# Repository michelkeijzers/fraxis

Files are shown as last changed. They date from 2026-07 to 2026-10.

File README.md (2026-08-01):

# README

This project's personal goal is to learn more about ESP32 with ESP-IDF programming.

The project is a retro style computer with instead of a screen a 5x72 LED matrix, two joysticks (for each player), an 20x4 display, a display for time and scoring per player and a button and some LEDs.
At a later stage also sound will be incorporated (passive buzzer, I2s microphone and speaker, mono).

The idea is to be able to show demos, games and tools.

# DOCUMENTATION

In the Docs folder, UML diagrams can be found.
Also an extensive document (Fraxis.odt) shows the design decisions and more information about the project.

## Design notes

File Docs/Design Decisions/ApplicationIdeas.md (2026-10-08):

# Application Ideas

## GAMES

### Amoeba

Both players try to protect their base from the amoeba. It starts at the center. It grows whatever are no his. Players can shoot with button length press to decide the speed and thus location of the defense.
When the amoeba reaches a player, the player loses.
Points based on amoeba growth on enemy side

### Reaction time

Led Screen lights up, players press button as far as possible.

### Pixel chaser

Players move towards lighted pixels to get points. Different colors. Pixels fade. Faded pixels explode lowering or pausing speed.

### Stacking Game

One line moves from left to right and then the next row back. The player has to stack the next row on top of the previous one. When the player misses, the next row is smaller. When the player misses too much, he loses.

Maybe horizontal is also fine, starting of with a very wide row.

See https://www.youtube.com/shorts/zlKPKK3Qink

### Frogger

Tbd
Scrolling probably works best

### Line Racer , Car racer

Tbd
Optionally with turns

### Tetris

5 columns or windowed.

### Tunnel navigator

Like car racer but horizontal. More irregular pattern and various heights.

Helicopter rescue

The players have to pick up people to be rescued and bring them back to base.
Max 6 can be picked up and loading and unloading takes time.
The players have one common pool of testers. The helicopters cannot hit each other.

### Flow

Like android game. Windowed

Geography

Educational
Fly over a highly zoomed in county and find city shown in display selected as dot. Windowed.

### Guess the country

Educational
Fly over a highly zoomed in and guess the country from a list in the display.
Windowed

### 1D pong

Really one d Pong, over five rows same

### Dungeon, Dare jump

Player starts under rough wall moving down. Left right to lower. Platforms to land on. When no platform, dead.
Platforms like crumbling stone, fixed wood, moving left or right platforms, trampoline.
Landing on spikes or spikes at top hitting, losing one life.
Source xiamen

### Tank war

starting at home, tank moves. Scrollable. Walls can be shot, enemy tanks as well. Enemy tanks come and change direction at wall hit. Impenetrable blocks. When hit, started from home again. Enemy tanks can be shot in two stages.
Source xiamen

### Fishing Captain

Horizontal. Boat on top center, not movable. Throw nets or catch fishes with bubbles. At bottom row a pearl opens up at times for points. Be aware of bombs. Goal is to catch certain fishes in time. Colors can be used
Show on side what amount and types of fishes are needed. Two players with two boats on each half center.
Source xiamen

### Five in a row

Scrollable.
Source xiamen

### Ball battle

Evading planets and comets, eating balls.
Eat smaller balls only, in Fraxis use intensity.
Maybe scrollable.
Fixed full board size
Source xiamen

### (Dragon soul ) tower defense

Various types of defense towers have to be placed. Various enemies coming in waves each with hp. Some enemies are resistant against certain defense towers types.
Points by killing enemies can be used to buy more defense towers.
Broken through enemies cost a life.
Source xiamen

### 2048

Check if colors and intensiteit can be used
Move left right up or down, 2 is added at random left or right I think
Source xiamen

### Intellectual box

Puzzle

Move over kind of walls, 4 directions by rolling over or rotate, forming a 1x1 or 2x1 form. Find and fall into destination hole. Red Square are not allowed to land, don't get with one pixel over the edge.
Score is amount of moves.

Source xiamen

### Surround Jett

Puzzle
A rabbit wants to escape. Rabbit moves, you place fence. Either rabbit escapes or is trapped, ie cannot move. Score is amount of moves.
Source xiamen

### Flood

A river in the center. Players shoot by using left and right joystick press time for distance. When wall is hit, enemy or friendly, water slowly spreads if connected to empty spot.
Some pixels can result in bigger breaches.
Also a wall pixel can have hit points.

### Base shooter

Players can shoot rockets via the five lanes. When two rockets hit they explode.
When enemy rocket reaches enemy, 1 point. Time based.
No more than a certain amount of rockets per player can be active. Then the player can not shoot.

### 1D Line Advancer

A line is shown in the middle. Alternately players use button joystick to add pressure to a ball.v when released, ball moves. When stopped at line moves toward other player. When line is at player s home, player loses.

### Rocket lander

A moon rocket has to be landed with limited energy and breaking enough. Too much brake, fuel empty and crash. Too less brake, hit velocity too high.

### Snake

Windowed

### Space invaders

Windowed

### Crossroads

Starting with one crossing. Player has to switch traffic lights. One main long road or maybe two or three. Tbd.
Cars come and go. Maybe different vehicles by colors having different speeds or acceleration speeds.
Level increase by more crossings.

### Maze

Tbd

### Pacman

Windowed

### Mine sweeper

Puzzle
Either 5x72 or less, or windowed.

### Find differences

Patterns, maybe more than two. Find differences in pixels, intensity
Source xiamen

### Mastermind

Tbd.

### Simon shows

Leds are shown for a short time. Player has to repeat it.

Maybe new pixels appear and disappear while players are adding their matching pixels.

### Roulette

Choose various types of bets with the Joystick placed on predefined spots on the led board. Joystick to select bet amounts shown on the tm display
Pressing a green area causes the player to end bets
When both players are finished, ball rolls over the first line with single numbers.

### Alien feeder

A line patterned alien moves down. To have it back off, the players have to select a puzzel with the same color as the lowest line of the alien.
In the free area pixels of random colors are shown, with at least one per five rows with the right color.
Selection a wrong color make the alien extend one line immediately.
When the alien r reaches a player, the other wins
The alien starts with one line and extends to each players directions.

### Pick the color

A color has to be picked. When switched, the lowest three led strips show way less, less, correct, more or wat more per red green and blue. Maybe only less, real or more is best
Time based

### Stock market

Five rows shows stocks, forecast etc.

### Company Tycoon

Columns show information.
Buy incoming goods, s sell outgoing
Get personnel, machines, space, marketing, customer forecast etc
Manual needed

### Summer Games

Like in commodore 64
Left right movement, starting slowly, going faster.

### Button Papegaai (Parrot?)

When players half of the led light, press button, release when off
Score is as soon as possible button press and release.
Over time, led leds light up and less intensity

## DEMOS

### Knight Rider

Typical. Speed and length of trace van be adapted by joystick.

### Galaxy

Blue and white and in-between dots show and fade.
Relaxing.
Alternatives: falling stars, suns, supernovas exploding.
Intensity and speed can be adapted by joystick. Button for intensity on off. When off, amount of lights is changed.

### Rainbow

Scrolling colors. Speed and diagonally speed can be adapted by joystick,.

### Matrix

Falling lines of rain

### Stroboscope

Joystick for light and speed.
Second joystick for off time and color mode? Or joystick button color mode.

### Conway game of life

Tbd

## TOOLS

### Color mixer

Joystick button for choosing rgb , direction for more or less.

### Led strip metronome

Tbd

### Banner

Text is entered by joystick. Banner shown on ledstrip. Joystick button changed color mode fixed, changing, and up down direction speed. Left right color.

Bluetooth keyboard

### Counter

Two users can use the joystick to increase our decrease their counter. Shown on tm1637 and on ledstrip.
Button also to increase.

### Countdown timer

Set by Joystick, digit by digit. Button to start. Time shown on ledstrip and display. Led strip also shows pixels decreasing to 0.

### Clock

Shows clock (date/time?)

### Simple draw

Joystick for direction. Button changes color.
Possibility to save it load pictures, not sure how.

### UTILITIES

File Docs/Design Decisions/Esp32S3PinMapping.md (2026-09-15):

# ESP32 Pin Management

## Kicad mismatch

There is a mismatch between both available symbols on the schema editor and the (single) foot print.

Below is the mapping which has been changed to support the correct foot print.

Order is top/bottom, left to right for a landscape placed ESP32 footprint.

| Footprint Name | Pin Nr | (Old) Schematics Name  | Function |
| --- | --- | --- | --- |
| (Bottom, left to right) | - | - | - |
| 3V3 | 1 | LNA_IN/RF | |
| 3V3 | 2 | VDD3P3 | |
| EN/RESET | 3 | | |
| GPIO4 | 4 | | |
| GPIO5 | 5 | GPIO0/BOOT | |
| GPIO6 | 6 | GPIO1/ADC1_CH0 | |
| GPIO7 | 7 | GPIO2/ADC1_CH1 | |
| GPIO15 | 8 | GPIO3/ADC1_CH2 | |
| GPIO16 | 9 | GPIO4/ADC1_CH3 | |
| GPIO17 | 10 | GPIO5/ADC1_CH4 | |
| GPIO18 | 11 | GPIO6/ADC1_CH5 | |
| GPIO8 | 12 | GPIO7/ADC1_CH6 | |
| GPIO3 | 13 | GPIO8/ADC1_CH7 | |
| GPIO46 | 14 | GPIO9/ADC1_CH8 | |
| GPIO9 | 15 | ?? | |
| GPIO10 | 16 | GPIO11/ADC2_CH0 | |
| GPIO11 | 17 | GPIO12/ADC2_CH1 | |
| GPIO12 | 18 | GPIO13/ADC2_CH2 | |
| GPIO13 | 19 | GPIO14/ADC2_CH3 | |
| GPIO14 | 20 | VDD3P3_RTC | |
| 5V | 21 | GPIO15/ADC2_CH4/XTAL.. | |
| GND | 22 | GPIO16/ADC2_CH5/XTAL.. | |
| (Top, right to left) | - | - | - |
| GND | 23 | GPIO17/ADC2_CH6 | |
| GND | 24 | GPIO18/ADC2_CH7 | |
| GPIO19 | 25 | | |
| GPIO20 | 26 | | |
| GPIO21 | 27 | GPIO21 | |
| GPIO47 | 28 | GPIO26/SPI_CS1 | |
| GPIO48 | 29 | VDD_SPI | |
| GPIO45 | 30 | GPIO27/SPIHD | |
| GPIO0 | 31 | GPIO28/SPIWP | |
| GPIO35 | 32 | GPIO29/SPICS0 | |
| GPIO36 | 33 | GPIO30/SPICLK | |
| GPIO37 | 34 | GPIO31/SPIQ | |
| GPIO38 | 35 | GPIO32/SPID | |
| GPIO39/MTCK | 36 | GPIO48/SPICLK_N | |
| GPIO40/MTDO | 37 | GPIO47/SPICLK_P | |
| GPIO41/MTDI | 38 | SPIO33 | |
| GPIO42/MTMS | 39 | SPIO34 | |
| GPIO02 | 40 | GPIO35 | |
| GPIO01 | 41 | GPIO36 | |
| GPIO44/UORXD | 42 | GPIO37 | |
| GPIO43/UOTXD | 43 | GPIO38 | |
| GND | 44 | GND | |

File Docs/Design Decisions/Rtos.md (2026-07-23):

# RTOS

# TASKS

Core 0: Time Critical
Core 1: Logic, UI, I/O, System

| Task | Contains | Core | Priority | Percentage | Notes |
| --- | --- | ---- | --- | --- | --- |
| LedStrips | WS2812 | 0 | Highest  | 5-15% | 60 Hz |
| Sound | MAX98357 speaker, INMP441 Mic, Passive Buzzer | 0 | High | 10-25% | 16 kHz, 16 bit, mono |
| I2C | MCP23017 (Joysticks, PinIO, LEDs, button), 2004 LCD | 1 | High | 3-10% | |
| Tm1637 | TM1637 (Central Panel, Player 1/2) | 1 | Medium | 2-6% | |
| Apps | Apps | 1 | Medium | 5-20% | |
| System | Menu, NVRAM, Logging, Settings | 1 | Low | 2-5% | |

# QUEUES

| Queue | Source | Destination  | Messages | Data | Notes |
| --- | --- | --- | --- | --- | --- |
| LedStripQueue | Apps | LedStrips | SetLeds | ledBuffer | - |
| | | | SetBrightness | level | - |
| SoundQueue | Apps | Sound | PlaySample | id | - |
| | | | Tone | frequency, duration | |
| | | | StopSound | | |
| | | | StartMic | | |
| | | | StopMic | | |
| I2CRequest | Apps, System | I2C | WriteLed | ledId, value | |
| | | | PrintLcd | line1, line2 | |
| | | | ClearLcd | | |
| I2CEvent | I2C | Apps, System | JoystickEvent | player, direction | |
| | | | ButtonEvent | id, pressed | |
| Tm1637 | Apps, System | Tm1637 | SetValue | id, value | |
| | | | SetTime | first, second | |
| System | System | Apps | RunApp | appId | |
| | Apps | System | ChangeSettings | Settings | |
| | | | UpdateHighscores | Highscores | |
| Logging | Any | System | Log | Source, type, logging text | Type = Error, warning, info, debug |

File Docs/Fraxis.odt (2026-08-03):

FRAXIS

Five Row Arcade eXperience
Interactive System

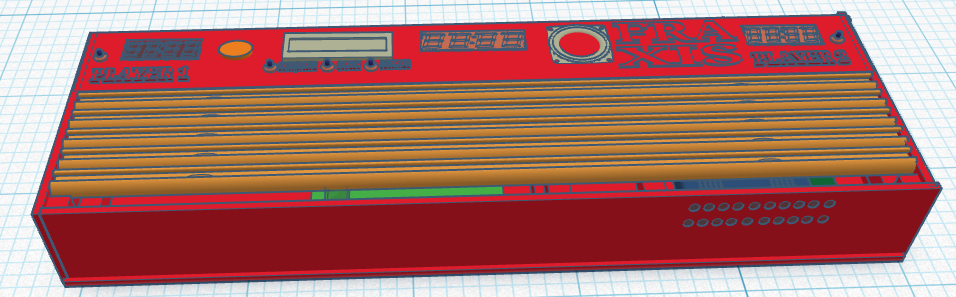
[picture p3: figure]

v0.12

Created by Michel Keijzers

Date July 7, 2026

Table of Content

1. Introduction (https://docs.google.com/document/d/1huFCTBTo_V-qLagU39WpXXM1eQROCzyZlzvM63dEwec/edit?tab=t.0)

2. Device (https://docs.google.com/document/d/1huFCTBTo_V-qLagU39WpXXM1eQROCzyZlzvM63dEwec/edit?tab=t.0)

3. Electrical (https://docs.google.com/document/d/1huFCTBTo_V-qLagU39WpXXM1eQROCzyZlzvM63dEwec/edit?tab=t.0)

4. Games (https://docs.google.com/document/d/1huFCTBTo_V-qLagU39WpXXM1eQROCzyZlzvM63dEwec/edit?tab=t.0)

4.1. Glossary (https://docs.google.com/document/d/1huFCTBTo_V-qLagU39WpXXM1eQROCzyZlzvM63dEwec/edit?tab=t.0)

4.2. Solo Games (https://docs.google.com/document/d/1huFCTBTo_V-qLagU39WpXXM1eQROCzyZlzvM63dEwec/edit?tab=t.0)

4.3. Two Player Games (https://docs.google.com/document/d/1huFCTBTo_V-qLagU39WpXXM1eQROCzyZlzvM63dEwec/edit?tab=t.0)

4.4. Both Solo/Two Player Games (https://docs.google.com/document/d/1huFCTBTo_V-qLagU39WpXXM1eQROCzyZlzvM63dEwec/edit?tab=t.0)

4.4.1. Pong (https://docs.google.com/document/d/1huFCTBTo_V-qLagU39WpXXM1eQROCzyZlzvM63dEwec/edit?tab=t.0)

4.4.1.1. Description (https://docs.google.com/document/d/1huFCTBTo_V-qLagU39WpXXM1eQROCzyZlzvM63dEwec/edit?tab=t.0)

4.4.1.2. Game Rules (https://docs.google.com/document/d/1huFCTBTo_V-qLagU39WpXXM1eQROCzyZlzvM63dEwec/edit?tab=t.0)

4.4.1.3. Scoring (https://docs.google.com/document/d/1huFCTBTo_V-qLagU39WpXXM1eQROCzyZlzvM63dEwec/edit?tab=t.0)

4.4.1.4. UI (https://docs.google.com/document/d/1huFCTBTo_V-qLagU39WpXXM1eQROCzyZlzvM63dEwec/edit?tab=t.0)

4.4.2. Controls (https://docs.google.com/document/d/1huFCTBTo_V-qLagU39WpXXM1eQROCzyZlzvM63dEwec/edit?tab=t.0)

4.4.3. Settings (https://docs.google.com/document/d/1huFCTBTo_V-qLagU39WpXXM1eQROCzyZlzvM63dEwec/edit?tab=t.0)

4.5. SIMON MEMORY (https://docs.google.com/document/d/1huFCTBTo_V-qLagU39WpXXM1eQROCzyZlzvM63dEwec/edit?tab=t.0)

4.5.1. Description (https://docs.google.com/document/d/1huFCTBTo_V-qLagU39WpXXM1eQROCzyZlzvM63dEwec/edit?tab=t.0)

4.5.2. UI (https://docs.google.com/document/d/1huFCTBTo_V-qLagU39WpXXM1eQROCzyZlzvM63dEwec/edit?tab=t.0)

4.5.3. Controls (https://docs.google.com/document/d/1huFCTBTo_V-qLagU39WpXXM1eQROCzyZlzvM63dEwec/edit?tab=t.0)

4.5.4. Scoring (https://docs.google.com/document/d/1huFCTBTo_V-qLagU39WpXXM1eQROCzyZlzvM63dEwec/edit?tab=t.0)

4.5.5. Settings (https://docs.google.com/document/d/1huFCTBTo_V-qLagU39WpXXM1eQROCzyZlzvM63dEwec/edit?tab=t.0)

4.6. REACTION SPEED (https://docs.google.com/document/d/1huFCTBTo_V-qLagU39WpXXM1eQROCzyZlzvM63dEwec/edit?tab=t.0)

4.6.1. Description (https://docs.google.com/document/d/1huFCTBTo_V-qLagU39WpXXM1eQROCzyZlzvM63dEwec/edit?tab=t.0)

4.6.2. UI (https://docs.google.com/document/d/1huFCTBTo_V-qLagU39WpXXM1eQROCzyZlzvM63dEwec/edit?tab=t.0)

4.6.3. Controls (https://docs.google.com/document/d/1huFCTBTo_V-qLagU39WpXXM1eQROCzyZlzvM63dEwec/edit?tab=t.0)

4.6.4. Scoring (https://docs.google.com/document/d/1huFCTBTo_V-qLagU39WpXXM1eQROCzyZlzvM63dEwec/edit?tab=t.0)

4.6.5. Settings (https://docs.google.com/document/d/1huFCTBTo_V-qLagU39WpXXM1eQROCzyZlzvM63dEwec/edit?tab=t.0)

4.7. Color Patterns (https://docs.google.com/document/d/1huFCTBTo_V-qLagU39WpXXM1eQROCzyZlzvM63dEwec/edit?tab=t.0)

4.7.1. Description (https://docs.google.com/document/d/1huFCTBTo_V-qLagU39WpXXM1eQROCzyZlzvM63dEwec/edit?tab=t.0)

4.7.2. UI (https://docs.google.com/document/d/1huFCTBTo_V-qLagU39WpXXM1eQROCzyZlzvM63dEwec/edit?tab=t.0)

4.7.3. Controls (https://docs.google.com/document/d/1huFCTBTo_V-qLagU39WpXXM1eQROCzyZlzvM63dEwec/edit?tab=t.0)

4.7.4. Scoring (https://docs.google.com/document/d/1huFCTBTo_V-qLagU39WpXXM1eQROCzyZlzvM63dEwec/edit?tab=t.0)

4.7.5. Settings (https://docs.google.com/document/d/1huFCTBTo_V-qLagU39WpXXM1eQROCzyZlzvM63dEwec/edit?tab=t.0)

4.8. Draw (https://docs.google.com/document/d/1huFCTBTo_V-qLagU39WpXXM1eQROCzyZlzvM63dEwec/edit?tab=t.0)

4.8.1. Description (https://docs.google.com/document/d/1huFCTBTo_V-qLagU39WpXXM1eQROCzyZlzvM63dEwec/edit?tab=t.0)

4.8.2. UI (https://docs.google.com/document/d/1huFCTBTo_V-qLagU39WpXXM1eQROCzyZlzvM63dEwec/edit?tab=t.0)

4.8.3. Controls (https://docs.google.com/document/d/1huFCTBTo_V-qLagU39WpXXM1eQROCzyZlzvM63dEwec/edit?tab=t.0)

4.8.4. Scoring (https://docs.google.com/document/d/1huFCTBTo_V-qLagU39WpXXM1eQROCzyZlzvM63dEwec/edit?tab=t.0)

4.8.5. Settings (https://docs.google.com/document/d/1huFCTBTo_V-qLagU39WpXXM1eQROCzyZlzvM63dEwec/edit?tab=t.0)

5. UI (https://docs.google.com/document/d/1huFCTBTo_V-qLagU39WpXXM1eQROCzyZlzvM63dEwec/edit?tab=t.0)

6. Software (https://docs.google.com/document/d/1huFCTBTo_V-qLagU39WpXXM1eQROCzyZlzvM63dEwec/edit?tab=t.0)

6.1. SRAM Memory Usage (https://docs.google.com/document/d/1huFCTBTo_V-qLagU39WpXXM1eQROCzyZlzvM63dEwec/edit?tab=t.0)

6.2. EEPROM Memory Usage (https://docs.google.com/document/d/1huFCTBTo_V-qLagU39WpXXM1eQROCzyZlzvM63dEwec/edit?tab=t.0)

6.3. Flash Memory Usage (https://docs.google.com/document/d/1huFCTBTo_V-qLagU39WpXXM1eQROCzyZlzvM63dEwec/edit?tab=t.0)

7. Electronics (https://docs.google.com/document/d/1huFCTBTo_V-qLagU39WpXXM1eQROCzyZlzvM63dEwec/edit?tab=t.0)

7.1. Components (https://docs.google.com/document/d/1huFCTBTo_V-qLagU39WpXXM1eQROCzyZlzvM63dEwec/edit?tab=t.0)

7.2. CPU Pin usage (https://docs.google.com/document/d/1huFCTBTo_V-qLagU39WpXXM1eQROCzyZlzvM63dEwec/edit?tab=t.0)

7.3. Power Usage (https://docs.google.com/document/d/1huFCTBTo_V-qLagU39WpXXM1eQROCzyZlzvM63dEwec/edit?tab=t.0)

8. Enclosure (https://docs.google.com/document/d/1huFCTBTo_V-qLagU39WpXXM1eQROCzyZlzvM63dEwec/edit?tab=t.0)

8.1. General (https://docs.google.com/document/d/1huFCTBTo_V-qLagU39WpXXM1eQROCzyZlzvM63dEwec/edit?tab=t.0)

8.2. Components (https://docs.google.com/document/d/1huFCTBTo_V-qLagU39WpXXM1eQROCzyZlzvM63dEwec/edit?tab=t.0)

8.3. MDF Plate cutting (https://docs.google.com/document/d/1huFCTBTo_V-qLagU39WpXXM1eQROCzyZlzvM63dEwec/edit?tab=t.0)

# Introduction

This device is called FRAXIS: Five Rows Arcade Experience Interactive System.

The goal of the device is to play games, although there will also be graphical/sound demos and utilities available.

The base of the system are five LED strips vertically or horizontally between two players. Also one player games will be supported.

# Device

The device is about 55 x 20 x 8 cm and contains:

- In the center, five 50 centimeter LED strips containing 72 * 5 RGB leds.
- To navigation the menu to select and adjust applications:
  - A text display (LCD) (for selecting game/settings)
  - Either joystick can be used for navigation.
  - Three LEDs for showing the mode or game states (play/paused).
- A central display mostly used during games with 4 digits to be able to show time.
- For each player:
  - A joystick that can be attached to the enclosure.
  - A display capable of showing 6 digits, e.g. for the score.
  - A small LED for player notifications.
- Audio control:
  - A buzzer for beeps.
  - A (mono) speaker for sound effects or better sound.
  - A (low profile) microphone for e.g. sound controlled applications.

Below is a sketch picture.

# Electronics

## Introduction

This chapter shows all schematics and PCB layout including many design decisions made.

## Schematics

### Overview

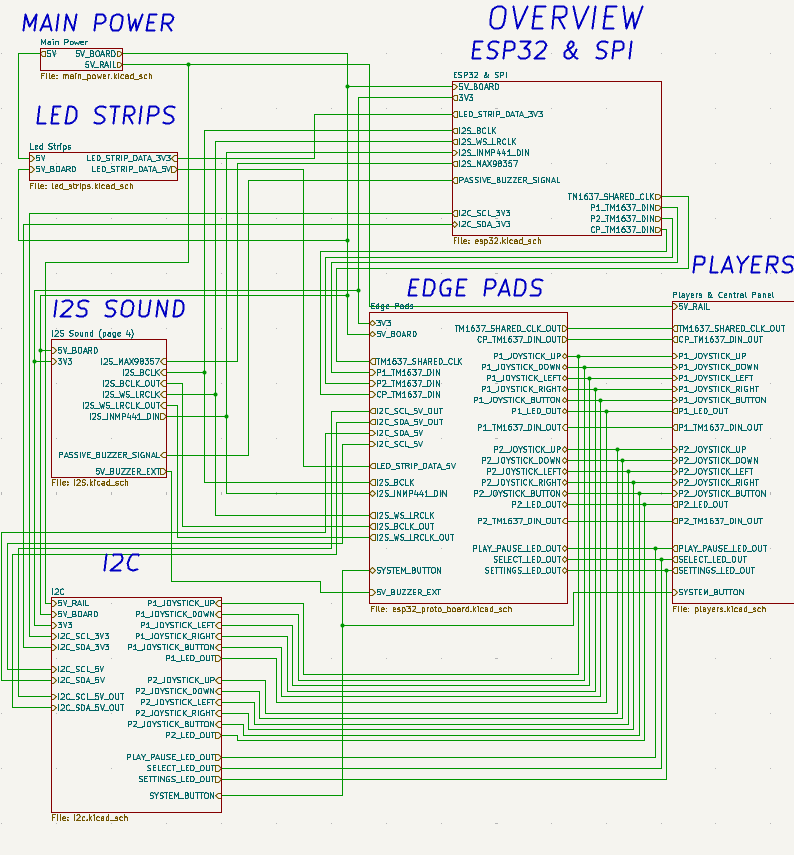
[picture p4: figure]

The system is built in various parts:

- Main power: Power plug, adapter, ground/5V to led strips and ESP32 proto board.
- LED Strips
- ESP32 & SPI (Micro SD Card Reader)
- I2S Sound: I2S microphone, amplifier, speaker and a passive buzzer
- Edge Pads: Edge pads of the ESP32 proto board
- Players: TM1637 displays, joysticks and LEDs
- I2C: MCP23017 GPIO expander, I2C level shifter and 1602 LED Display

The design decisions are explained in the corresponding paragraphs.

### Main Power

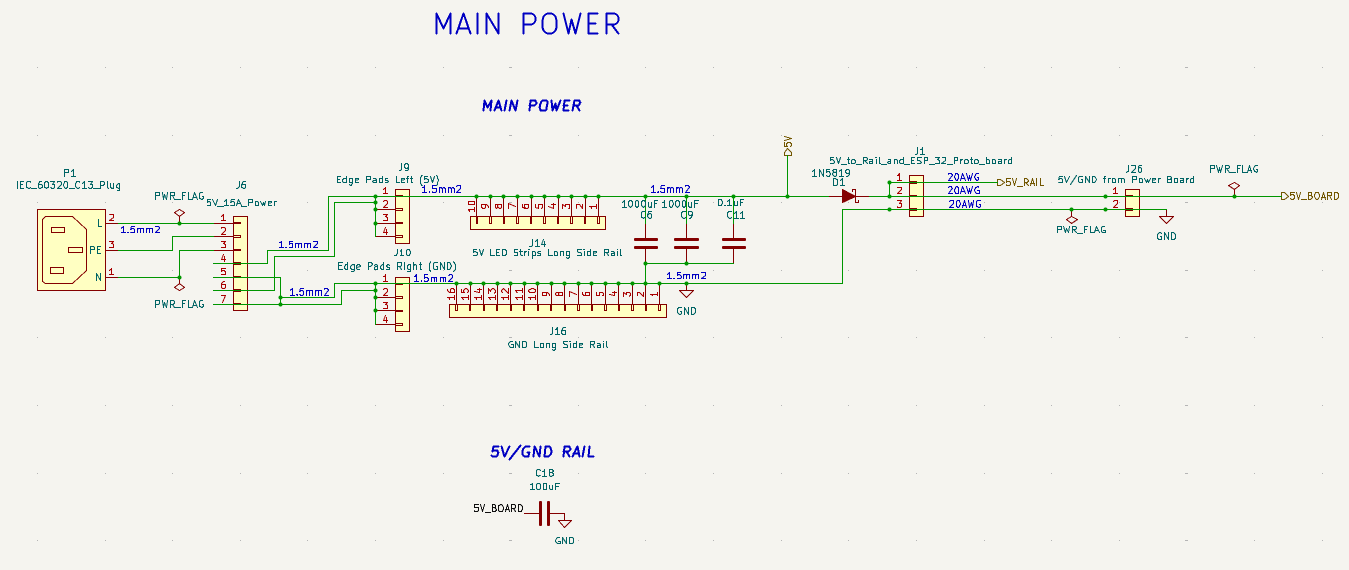
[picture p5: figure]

The main power comes from a IEC320 plugin to provide 220-240V/50-60 Hz. This is slightly overkill, however, that plugin comes with a builtin switch and light to see it’s switched on.

There are mainly two power consuming elements: the LED strips which take up far the most current and the processing board, called ESP32 proto board.

Since this device will not be a full display device and will be mostly used inside, full brightness is not needed. However, to be able to create interesting applications, 5 rows of 72 LEDs will be used meaning 360 LEDs. Each LED maximum can use 60 mA (20 mA) per color, resulting in 21.6 A. However, since not full brightness is needed, an adapter of 10A will be used, where the ESP32 proto board can use upto 1.5A (both 3.3V and 5V components combined) and 2A is used as headroom. This results in max 6.5A to be used for the LED strips.

The adapter has two V+ and V- output ports which are laid in parallel to each side of a small so called Power proto board where two thick copper wires are serving as 5V and GND rails.

Capacitors are added and on the side rails 5V and GND can be taken for the LED strips and 5V for devices (such as the 1602 LCD and TM1637 displays).

A special terminal block is used to provide 5V/GND towards the ESP32 proto board. This power is led through a diode to prevent accidental power reverse.

For a rough calculation of the current needs for the proto board and related 3V3 components, below is a list. As can be seen, it’s well under 1.5A, especially as the WIFI capability on the ESP32 will be used only for OTA updates and the microSD Card Reader will only be used occasionaly.

Component | Current (mA) | Comment
ESP32 | 500 | Peaks when using WIFI
MCP23017 module | 2
74AHCT125 | 5
I2C Level shifter (BSS138) | 1
I2S MAX89753 amplifier | 600
I2S INMP441 microphone | 2
MicroSD Card Reader | 100
Total | 1210

Regarding 3V3 components to be powered by the AMS1117, the list is:

Component | Current (mA) | Comment
MCP23017 module | 2
74AHCT125 | 5
I2C Level Shifter (BSS138) | 1
INMP441 microphone | 2
MicroSD Card Reader | 100
Total | 110

3.3V Power through AMS1117:

P_3.3V,load = 3.3V⋅0.11A ≈ 0.36 W

Power dissipation of AMS1117:

P_AMS1117= (5V −3.3V)⋅0.11A ≈ 0.19 W

For 0.19W, no heat sink is needed.

### LED Strips

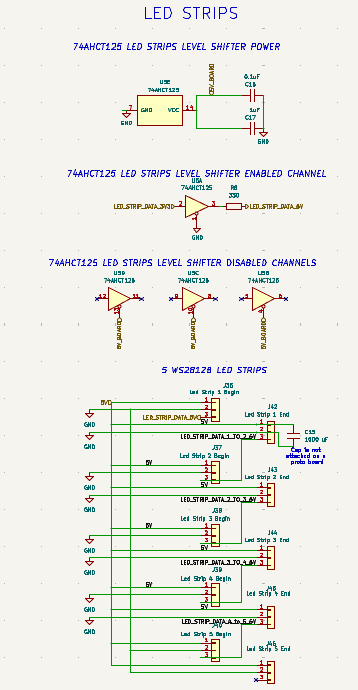
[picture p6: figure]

Five 50 cm WS2812B led strips will be used. Because the enclosure should not become too long but still many LEDs should be present, 144 LEDs/m strips will be used, which are cut in half resulting in 5 rows of 72 LEDs each, totalling 380 LEDs. In the Power schematics you can read about the power consumption.

WS2813 is not needed as the chance of a breaking LED is fairly low. The strips will be placed inside aluminium strips, therefore no water protection is needed, anything from IP20 will do.

The reason that five LED strips are selected have a non electronics reason (always a central row and three rows would feel too limited).

Since the LED strips are enclosured, the chance of a LED failing is low, so WS2812B is selected over WS2813.

One big chain will be used instead of five separate LED strip channels, otherwise two level shifters would be needed.

To reduce the length of the LED strip length, the begin and end of each LED strip is laid out alternated.

LED STRIP 1 Begin -------------------------------→ LED STRIP 1 END --\
/--LED STRIP 2 End ←--------------------------------- LED STRIP 2 BEGIN <-/
\->LED STRIP 3 Begin -------------------------------→ LED STRIP 3 END --\
/--LED STRIP 4 End ←--------------------------------- LED STRIP 4 BEGIN <-/
\->LED STRIP 5 Begin -------------------------------→ LED STRIP 5 END

This reduces the total length of the LED strips chain to 250 cm excluding the distance from the ESP32 proto board.

Because of this length, some measurements need to be taken:

- Big capacitors are needed and are placed both on the Power proto board and a big capacitor at the other end (where is the start of the LED strips).

- A level shifter is used: an 74AHCT125. Only one channel is used. The used channel must be connected to enable with GND. The unused channels MUST be connected (with 5V). The unused channels input/output are not allowed to be connected.

- 5V is injected at both ends of each LED strip.

### I2S Sound

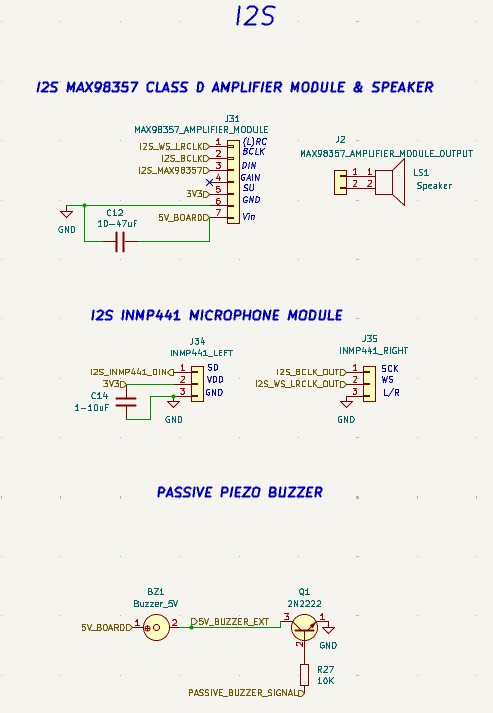
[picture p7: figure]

Two sound production components will be used:

- A passive buzzer, capable of making simple sounds, with varying frequencies but mostly usable for beeps and higher pitched sounds, definitely not high quality.

- A MAX89357 module connected to a 3W 4Ohm 40mm speaker for higher quality sounds, although bass quality is still limited. A special box enclosure will be made to improve the bass pressure.

The amplifier has its own output via a two pins terminal block, so it will not be broken out on an edge pad.

One microphone is used: a INMP441 microphone module.

Since I2S lines are critical, all external wires (to the microphone) will be twisted with specific GND wires.

The passive buzzer will be used with 5V to increase the power, otherwise it will be mainly overpowered with the amplifier/speaker combination:

Source | Assumptions | Approx. SPL @ 30 cm
MAX98357 + 3 W / 4 Ω speaker | Speaker sensitivity ~86 dB @ 1 W/1 m, driven near 3 W @ 5 V | ≈ 100–102 dB
Passive buzzer @ 3.3 V | Typical small piezo: ≈ 75 dB @ 10 cm at 3.3 V | ≈ 65 dB
Passive buzzer @ 5 V | +3.5 dB vs 3.3 V → ≈ 78.5 dB @ 10 cm | ≈ 69 dB

To increase the buzzer’s output (relative to the amp), the following design decisions are made:

- A transistor (2N2222) and resistor are used to be able to drive the buzzer at 5V.

- Software advice: use frequencies around the resonation spot, around 2-4 kHz.

- Enclosure advice: Place buzzer under small whole in enclosure (not on ESP32 proto board).

Note that longer wires do not affect quality and do not need to be twisted with GND.

The buzzer will be powered from the 5V rail.

### I2C

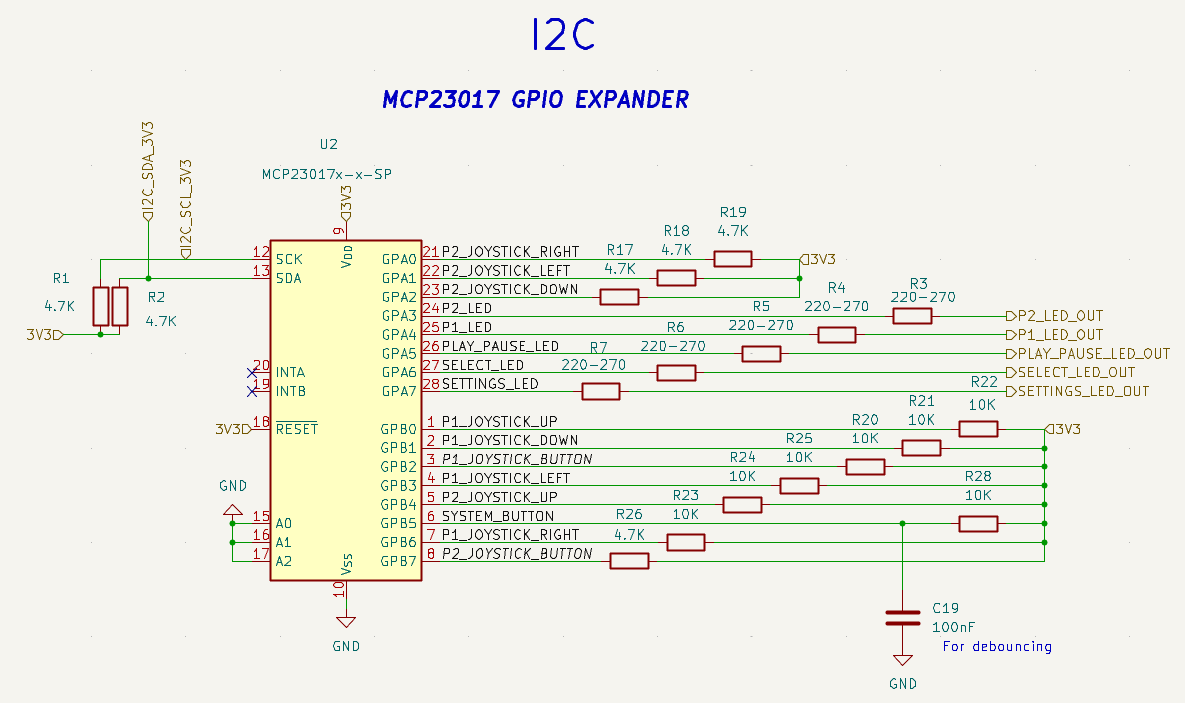
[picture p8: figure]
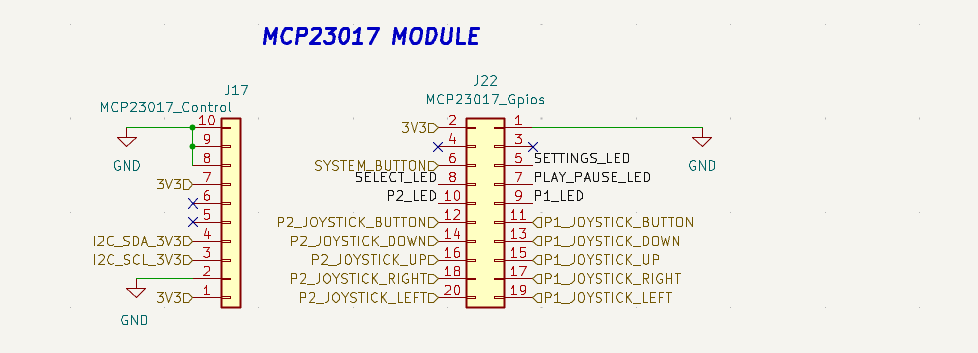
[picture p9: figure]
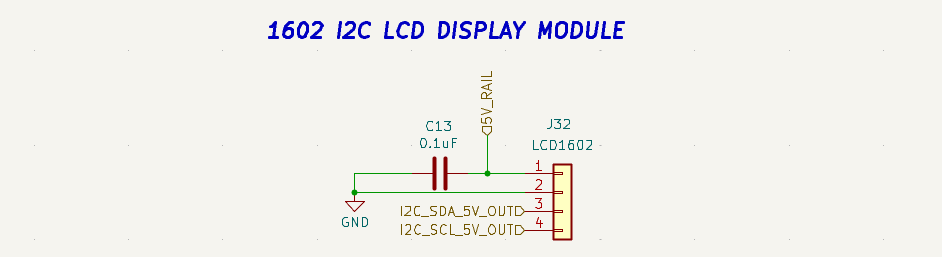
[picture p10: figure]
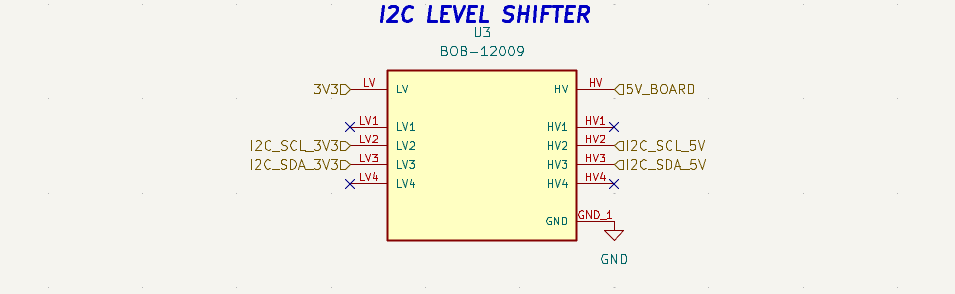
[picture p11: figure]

There will be two I2C components:

- An MCP23017 GPIO Expander, needed to handle the inputs of the two player joysticks and all LEDs. This is to reduce the number of pin usage on the ESP32.

- An 1602 LCD Display to be able to navigate the menu. Two lines of 16 characters each should suffice.

The MCP23017 works on 3.3V, but the 1602 LCD Display only works on 5V (otherwise at least the background display does not light). The 1602 LCD Display will be powered from the 5V rail.

Therefore a level shifter is needed, and the 74AHCT125 is not usable as it is one directional, where a BSS1338 level shifter is typically used for I2C line conversion. Only for the 3.3V side pulldowns are necessary, for the 1602 LCD Display, the existing ones built into the module will be used.

For the MCP23017, below is a table of used inputs/outputs.

Pin Function | Amount of pins | Mandatory
Joystick Player 1: Up, Down, Left, Right, Button | 5 | Yes
Joystick Player 2: Up, Down, Left, Right, Button | 5 | Yes
LED for Player 1 and 2 | 2 | Yes
Status LEDs: Select, Play/Pause, Setup | 3 | No
Unused | 1 | No

The status LEDs are used as there were pins available anyway. The exact function can be changed later when felt necessary. 220-270 ohm resistors are used, however this may depend on the color and brightness needed.

All inputs from the joystick need pullup resistors. Note that the MCP23017 has pullup resistors, however these are too weak for long wires.

The System button has a capacitor (close to the button, not MCP23017). This is to prevent the need for software debouncing.

The I2C wires need to be protected with twisted GND wires.

The joystick inputs also need to be protected, however one GND wire per joystick wire ‘bundle’ will suffice.

### ESP32 & SPI

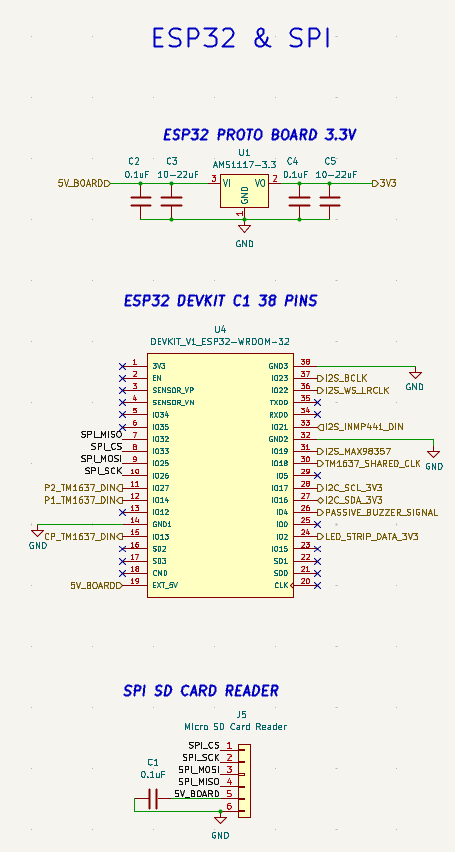
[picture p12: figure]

Looking at the vast amount of peripherals and pins needed, and the processing power need, and WIFI connection (for possible OTA updates), the ESP32 is a good candidate. An ESP32 Supermini C6 would be too limited regarding pins, but the ESP32 WROOM DevKit C1 has everything needed.

To prevent soldering issues, a full development board will be soldered on the ESP32 proto board (although with female pin headers for soldering heat protection and easy replacement).

To prevent using too much 3.3V power, it is not drawn directly from the ESP32.

The following components use 3.3V power:

Component | Current Consumption
MCP23017 | 2
74AHCT125 | 5
I2C Level Shifter | 1
INMP441 I2S Microphone | 2
MicroSD Card Reader | 100
I2C pullups on 3.3V | 2
Total | 112

The ESP32 DevKit C1 can produce about 250-300 mA, theorethically 500 mA but that heats up the regulator. Since the ESP32 is using 200-300 mA during a WiFi burst, there is almost no spare current left. Therefore, an AMS1117 will be used, using various capacitors around it according to the reference design.

Below is a full ESP32 pin out table including design decisions.

Pin Nr | GPIO Name | Connected | Rationale
1 | 3V3 | - | Unconnected, as the AMS1117 provides 3V3 power.
2 | EN | - | Default kept to the correct value.
3 | SENSOR_VP | -
4 | SENSOR_VN | -
5 | IO34 | -
6 | IO35 | -
7 | IO32 | SPI_MISO | SPI functions can be connected to almost any pin
8 | IO33 | SPI_CS | SPI functions can be connected to almost any pin
9 | IO25 | SPI_MOSI | SPI functions can be connected to almost any pin
10 | IO26 | SPI_SCK | SPI functions can be connected to almost any pin
11 | IO27 | P2_TM1637_DIN | TM1637 functions can be connected to almost any pin
12 | IO14 | P1_TM1637_DIN | TM1637 functions can be connected to almost any pin.
13 | IO12 | -
14 | GND1 | GND | All GND pins must be connected to ground.
15 | IO13 | CP_TM1637_DIN | TM1637 functions can be connected to almost any pin.
16 | SD2 | -
17 | SD3 | -
18 | CMD | -
19 | EXT_5V | 5V | 5V_BOARD is used, i.e. the power that comes from the Power proto board (and is diode protected).
20 | CLK | -

21 | SD0 | -
22 | SD1 | -
23 | IO15 | -
24 | IO2 | LED_STRIP_DATA_3V3 | This is a strapping pin. The LED strips keep this pin low during boot which means normal boot.
25 | IO0 | -
26 | IO4 | PASSIVE_BUZZER_ SIGNAL | This pin can be used for the passive buzzer without any limitations.
27 | IO16 | I2C_SDA_3V3 | Preferred pin for I2C SDA.
28 | IO17 | I2C_SCL_3V3 | Preferred pin for I2C SCL.
29 | IO5 | -
30 | IO18 | TM1637_SHARED_CLK | TM1637 functions can be connected to almost any pin

31 | IO19 | I2S_MAX98357 | This pin can be used for I2S without any limitations.
32 | GND2 | GND | All GND pins must be connected to ground.
33 | IO21 | I2S_INMP441_DIN | This pin can be used for I2S without any limitations.
34 | RXD0 | -
35 | TXD0 | -
36 | IO22 | I2S_BCLK | This pin can be used for I2S without any limitations.
37 | IO23 | I2S_WS_LRCLK | This pin can be used for I2S without any limitations.
38 | GND3 | GND | All GND pins must be connected to ground.

Note that I2S bus is shared. This means that the I2S frequency/sample rate is used for both the microphone and amplifier, which will be set to 16 kHz and 16 bit sampling.

### Edge Pads

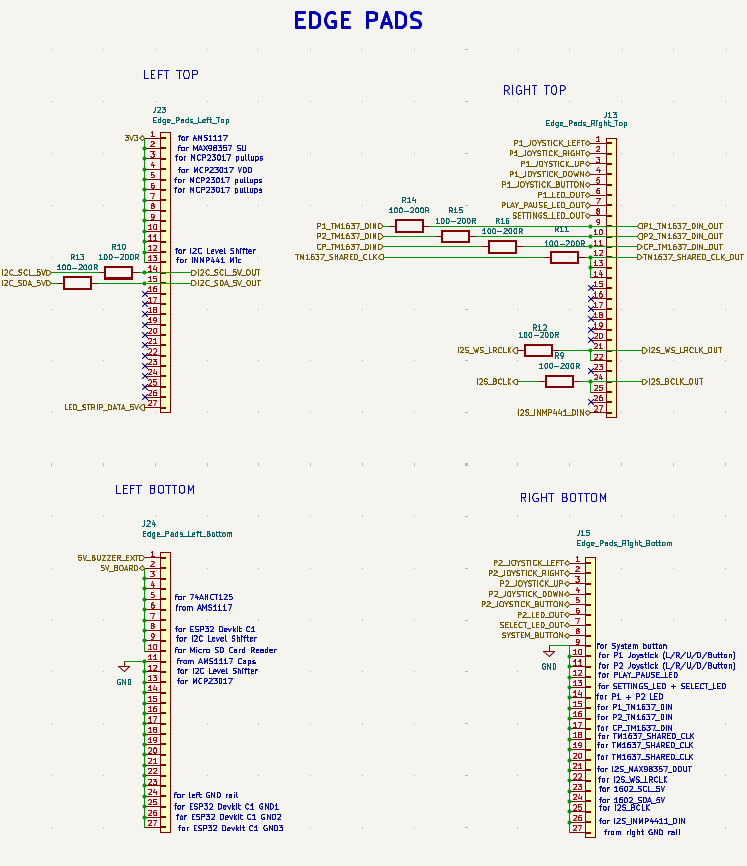
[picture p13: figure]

On both sides of the ESP32 proto board are edge pads, 27 in one row. Both the top and bottom side can be used, giving 27 * 2 * 2 = 108 pads.

On the left side mostly 3V3, 5V and GND is used. Some exceptions are:

- I2C: Since the converter is on that side of the proto board and the other side is pretty much filled.

- LED Strip data: The LED strip signal is important and LED strip 1 begins left of the proto board.

- Note that several pins from the left top side are blocked by the MicroSD Card Reader.

On the right side, mostly signals are used, and GND that serves as wires to twist around the signal on the other side on the top side of the edge pad. Although there are 108 pads available, the signal pins have each one pad, both for the internal routing (typically to the ESP32), and external (to the component in the enclosure top).

For various signals and due to long wires, resistors are used to keep the signal clean.

For most signals on this side, the location is to make sure wiring distance is minimal.

I2S clock pins are doubled to split between INMP4441 Microphone and MAX89357 amplifier.

### Players & Central Panel

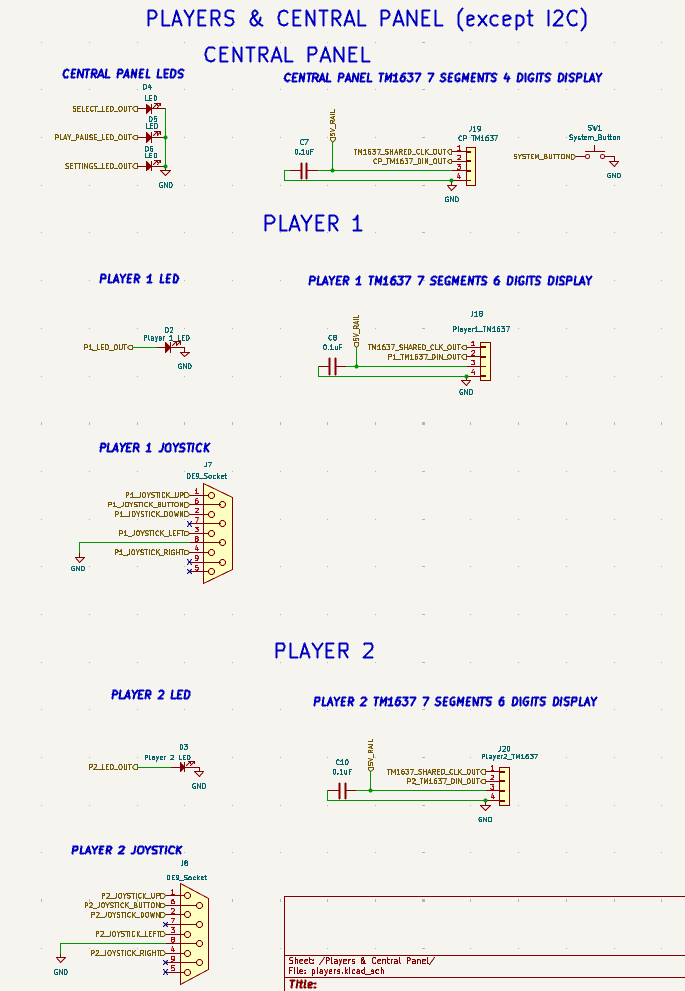
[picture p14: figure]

This page consists of both the player controls/feedback and central panel visual feedback with the exception of the 1602 LCD Display which is handled in the I2C section.

The following items are present:

- Central Panel LEDs: 3 LEDs with functions Select, Play/Pause and Settings, although these function can be changed during the project when necessary. Note that the limiting resistors are placed on the I2C schematics page, as they are coupled to the MCP23017.
- Central Panel: TM1637 Seven Segments display. All displays are 0.56” instead of the default 0.36” to allow for better reading during arcade games. This display can show 4 digits and has a colon in the middle so it can show time.
- Player 1 and Player 2 LED: this is a 3mm led that can be used for notifications
- Player 1 and Player 2 TM1637 Seven Segments display. This display has 6 digits so it can show higher value scores. It does not have a colon so a time would be represented as 12.34 instead of 12:34.
- Player 1 and Player 2 joysticks. These are Atari 2600 style joysticks with the micro switches for Up, Down, Left, Right, (Fire) Button. They need pullup resistors which are placed on the I2C schematics page. Software advice: likely software switch debouncing is not necessary, except for menu navigation possibly as the debounce time is 2-3 ms which can be too much for short movements. The joysticks are connected on the enclosure via DB9 connector mounted plugs.
- A system button which is used to activate the menu during a running app. E.g. in games, high likely both joysticks are active simultaneously and creating a kind of ‘tricky’ joystick combination is not intuitive and can lead to unexpected user experiences.

## PCB

### Overview

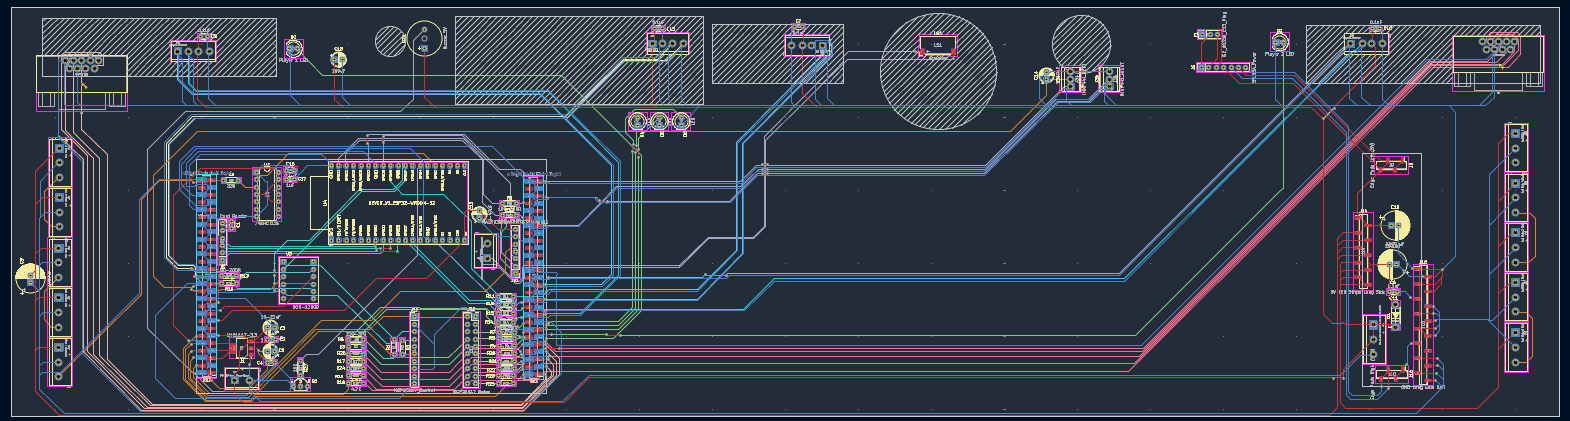
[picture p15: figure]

Above an overview is shown. In the top row there are the components which are visible typically for the players.

On the outmost left and right side there are five led strip begin/end headers depicting the LED strips.

On the right inwards is the Power proto board. On the left side is the ESP32 proto board.

Conventions:

- Since handsoldering and manual routing wires mean there are no layer restrictions, layers are used to be able to place wires over each other as will.
- For the ESP32 proto board, most wires have been laid around the board, even internal ones, to not clutter up the space.
- Thicker wires are 18-22AWG, otherwise 26AWG is assumed.
- The locations and dimensions are not fully according reality but show an indication.

In the next paragraphs a few closeups of specific areas are shown.

### Power

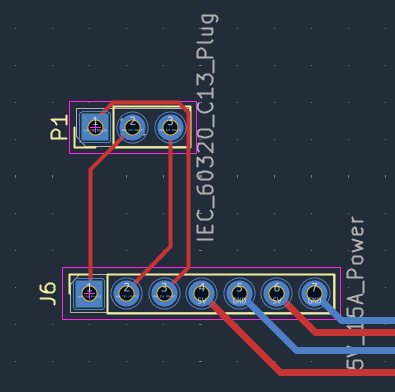
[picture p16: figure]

Above, the power (IEC320) plugin is shown as a 3 pin header. The 7 pin header is the 5V/10A adapter which has 220-240V Left/Right, GND pin, and two V+ and V- supplying 5V.

### Power Proto Board

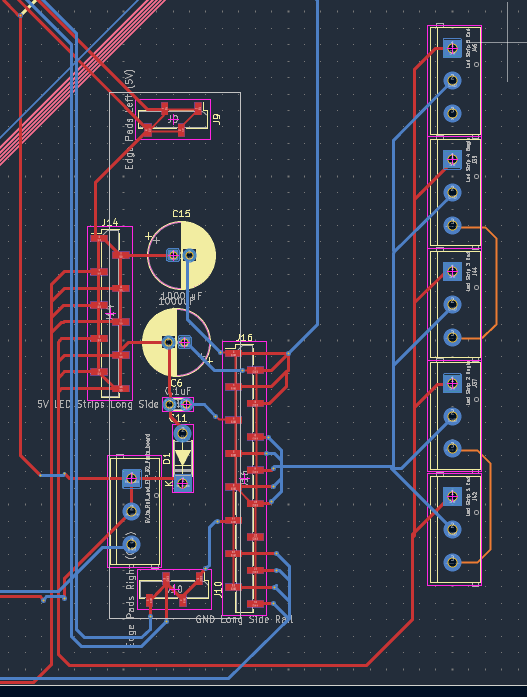
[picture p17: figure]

Above the Power proto board is shown. The wires in the top left are for the power adapter. Instead of the edge pads, probably a big copper strip will be solderd over each side giving more stability. These provide power for the LED strips. On the right you can see the connection from that half of the LED strips from the power proto board.

## ESP32 Proto Board

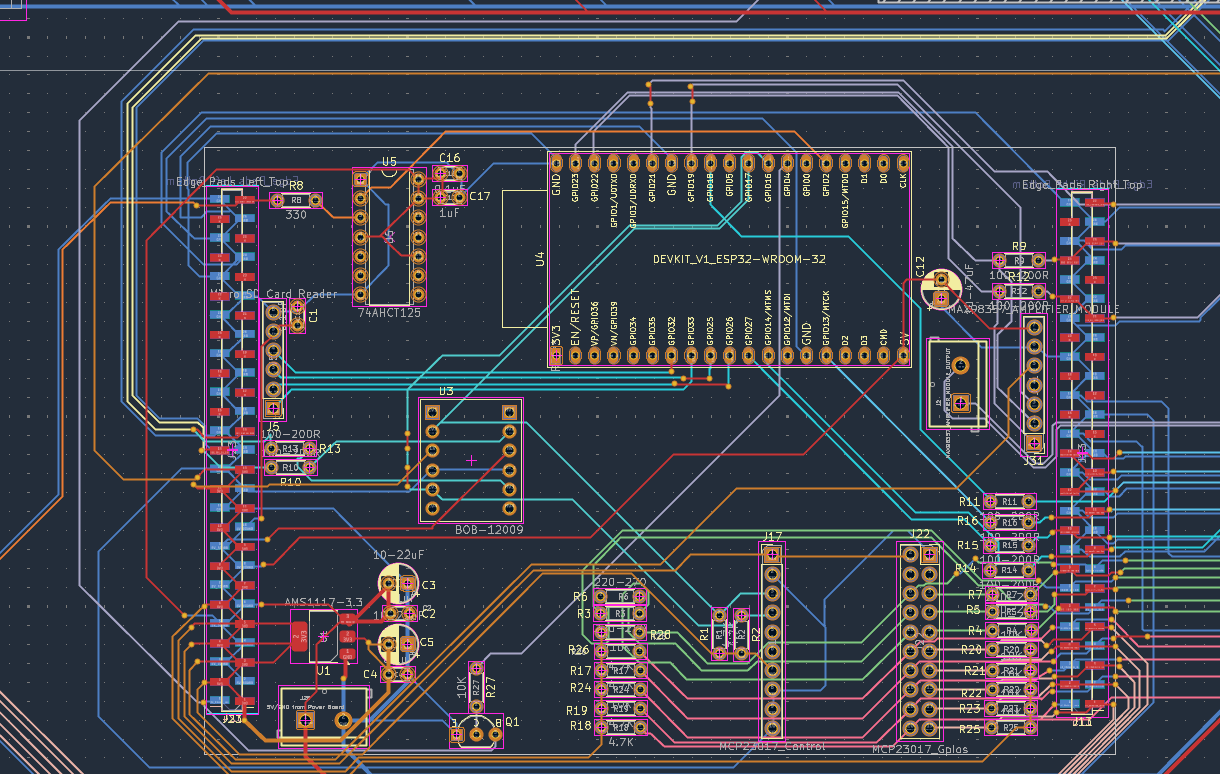
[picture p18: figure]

The picture above shows the ESP32 Proto Board.

- On the sides the edge pads are shown, both used on the top and bottom side for more signals.
- In the lower left the AMS1117 regularor is placed together with some capacitors.
- Right of it, pullup and line resistors are used and connected to the MSP23017 which is depicted as a 1x8 and 2x8 pin header.
- Above the right pullup resistors is the I2S amplifier module. The two gate terminal block shows the speaker in/out from that amplifier module.
- Left above the amplifier module is the ESP32 development kit WROOM C1. It is located in this way to make room for the micro USB cable in case needed and on the left to leave space for the antenna area.
- On the left of the ESP32 is the 74HC125N level shifter for the LED strips signal.
- Lower between the ESP32 and 74HC125N, the level shifter for I2C is placed.

## Bill of Materials

1. ESP32 WROOM DevKit C1
2. 2.5m of 144 leds/m WS2812B LED strips cut in 5 times 50 cm, resulting in 250 cm having 72 * 5 = 360 LEDs.
3. 5 x 50 cm LED strip holders
4. 2 x 6 digit seven segments display, 0.56”, TM1637 controlled.
5. 1 x 4 digit seven segments display, 0.56”, TM1637 controlled.
6. 1602 LCD Display, I2C controlled by I2C
7. I2C Level Shifter
8. MCP23017 GPIO Expander
9. MAX98357 Amplifier module.
10. 4W 4ohm 40mm speaker.
11. INMP441 Microphone module.
12. 2 x Atari 2600 style joysticks using DB9 connectors
13. 5 x 3mm LEDs, color to be decided.
14. FC4 Protoboard 8x12 cm
15. FC4 Protoboard 2x8 cm
16. Small electronic components, like resistors, capacitors, diodes, small transistors etc.
17. Tie wraps, cable markers etc.
18. Wire (18-22AWG and 26AWG)
19. Passive Buzzer.
20. 5V adapter, 10A
21. IEC320 plug.
22. Wooden enclosure using MDF
23. Wooden strengthening blocks/ribs.

# Enclosure

## Introduction

The enclosure will look like the front page which is copied here:

The picture below shows the back side:

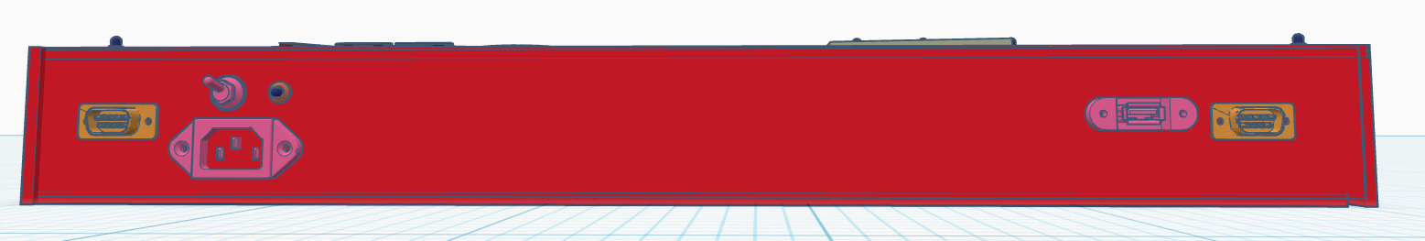
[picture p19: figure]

Note that the switch/LED/power plugin will be replaced by a ‘all in one’ IEC320 connector with switch and light.

On the inside, below the LED strips a wooden MDF plate will be assembled, which connects to the proto boards and adapter. Reinforcement ribs and bridges will be used. See pictures below.

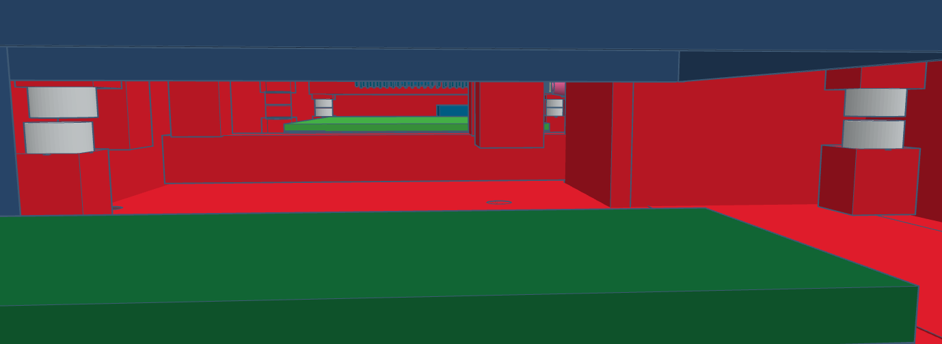
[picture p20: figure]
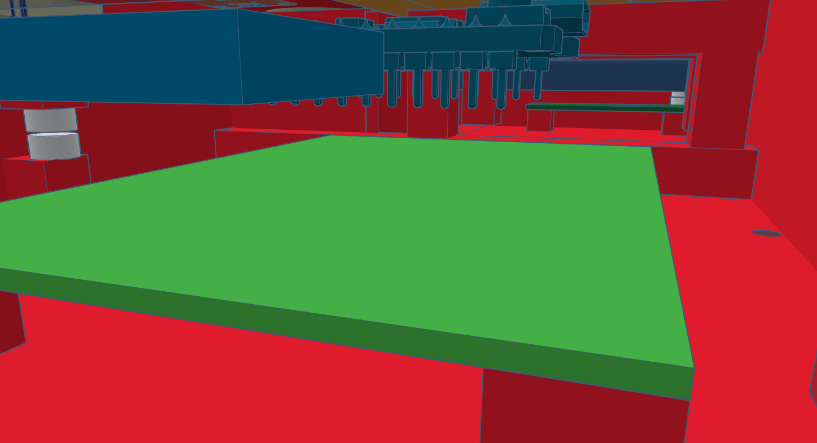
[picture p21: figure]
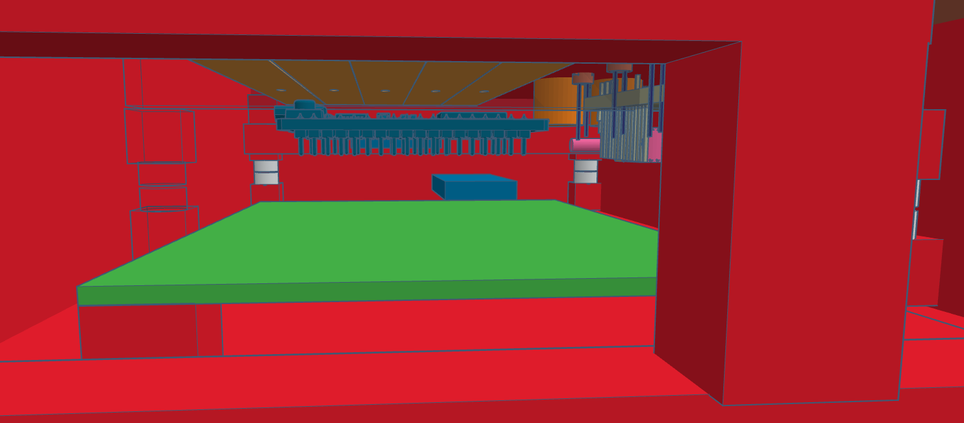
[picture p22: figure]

Note in these pictures, the proto board/adapter have not been connected to the top plate but still to the bottom plate.

## Construction Material

No 3D printing is used although it would be the esthetically best solution, because:

- The length of the enclosure is more than 50 cm, meaning not many printers can handle this.
- The size of th enclosure would make it expensive.
- Out of scope for this project.

Therefore, wood is used. To reduce the costs, MDF will be used for most ‘platework’ and glue/corner blocks and reinforcement ribs will be made from a wooden strip.

## Enclosure Opening

Since the board probably needs to be ropened for fixes/adaptations initially and creating a sort of esthetically opening on the side is hard, the entire bottom plate will be fixed with magnets. By holes in the bottom fingers can be used to pull the bottom plate by overcoming the magnetic strength.

To prevent the wires from being pulled, both proto boards and the adapter will be attached to the top instead of attached to the bottom plate. Tie wraps and/or other means will be used to fix them.

## Properties

1. Dimensions: approximately 530 x 180 x 70 mm
2. Weight: unknown

## Components

The following material is used:

- MDF wooden plate,122 x 61 cm, 4 mm

https://www.karwei.nl/assortiment/mdf-plaat-122-x-61-cm-4-mm/p/B340344
Rationale: normal wood is too heavy, 4 mm is more than enough.

- Wooden strip/batten, spruce, planed (smooth), 12 x 12 mm, 210 cm https://www.gamma.nl/assortiment/lat-vuren-geschaafd-12x12-mm-210-cm/p/B159292 Spruce (Dutch: Vuren) is high quality wood but not too hard so easy to saw, 12 x 12 mm is a practical size for ribs/corner blocks without becoming too big. Being planed smooth (Dutch: Geschaafd) is a must.
- Wooden glue (D2/D3): The need of screws or nails is not necessary.
- Magnets: to keep the bottom plate attached to the enclosure.
- Paint (optionally).

MDF Plate
Item | Amount | Width | Length | Area
Front/back plate | 2 | 640 | 120 | 153,600
Long vertical plates | 2 | 640 | 70 | 89,600
Short vertical plates | 4 | 120 | 70 | 33,600
Strengthening blocks | 20 | 15 | 15 | 4,500
Total | | | | 281,300
MDF Plate | 1 | 1,220 | 610 | 409,000
Left | | | | 127,700
Left (%) | | | | 31.2%

# Applications

## Introduction

There are various types:

- Games
- Utilities
- Demos
- Settings

## Navigation

The central panel joystick can be used to navigate:

- Left returns to the parent menu
- Right moves into the selected menu.
- Up moves the menu one menu option higher
- Down moves the menu one menu option lower
- Press is unused (so far)

## Structure

### Introduction

The menu has the following structure:

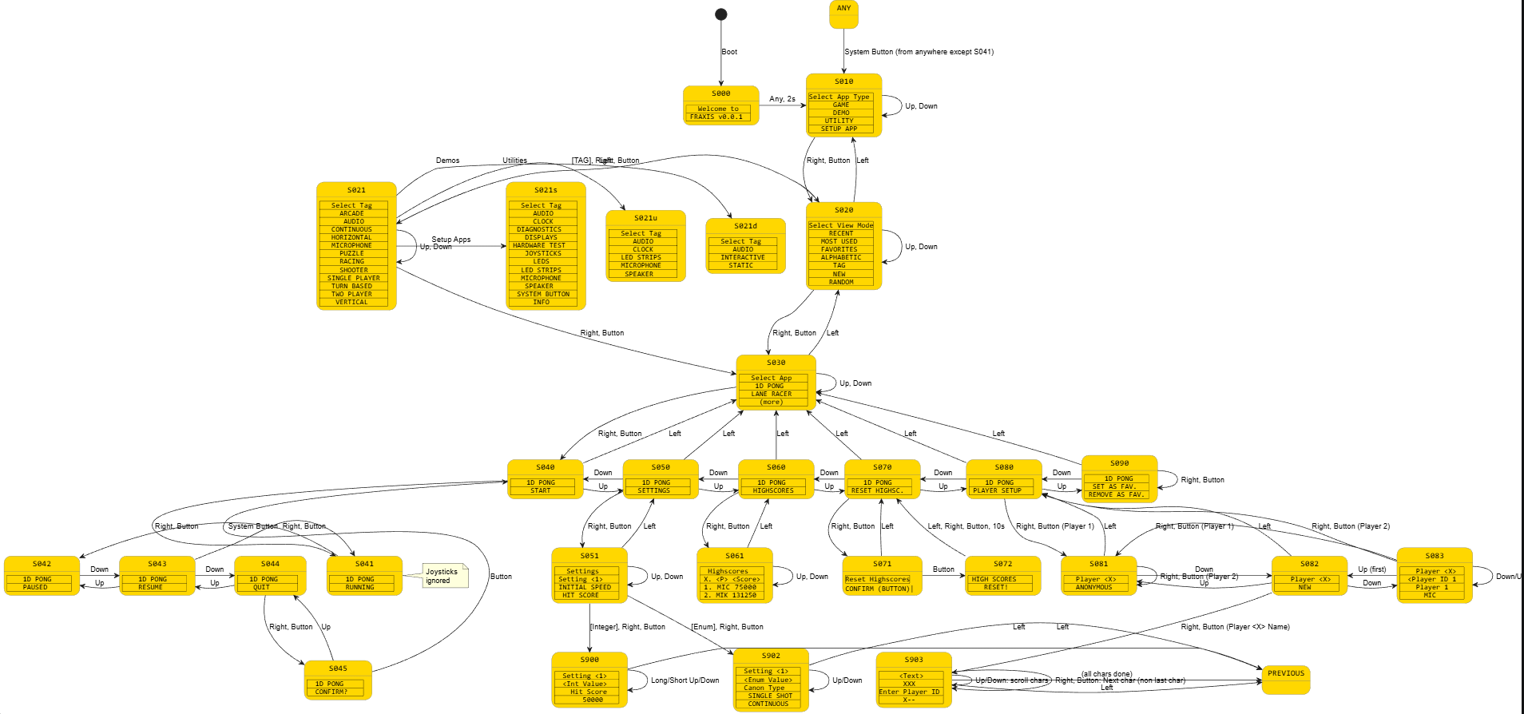
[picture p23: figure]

The diagram above can be split in three parts which will be covered in detail in the next paragraphs:

- App Selection
- App Execution
- App Management

### App Selection

The following diagram shows the app selection part:

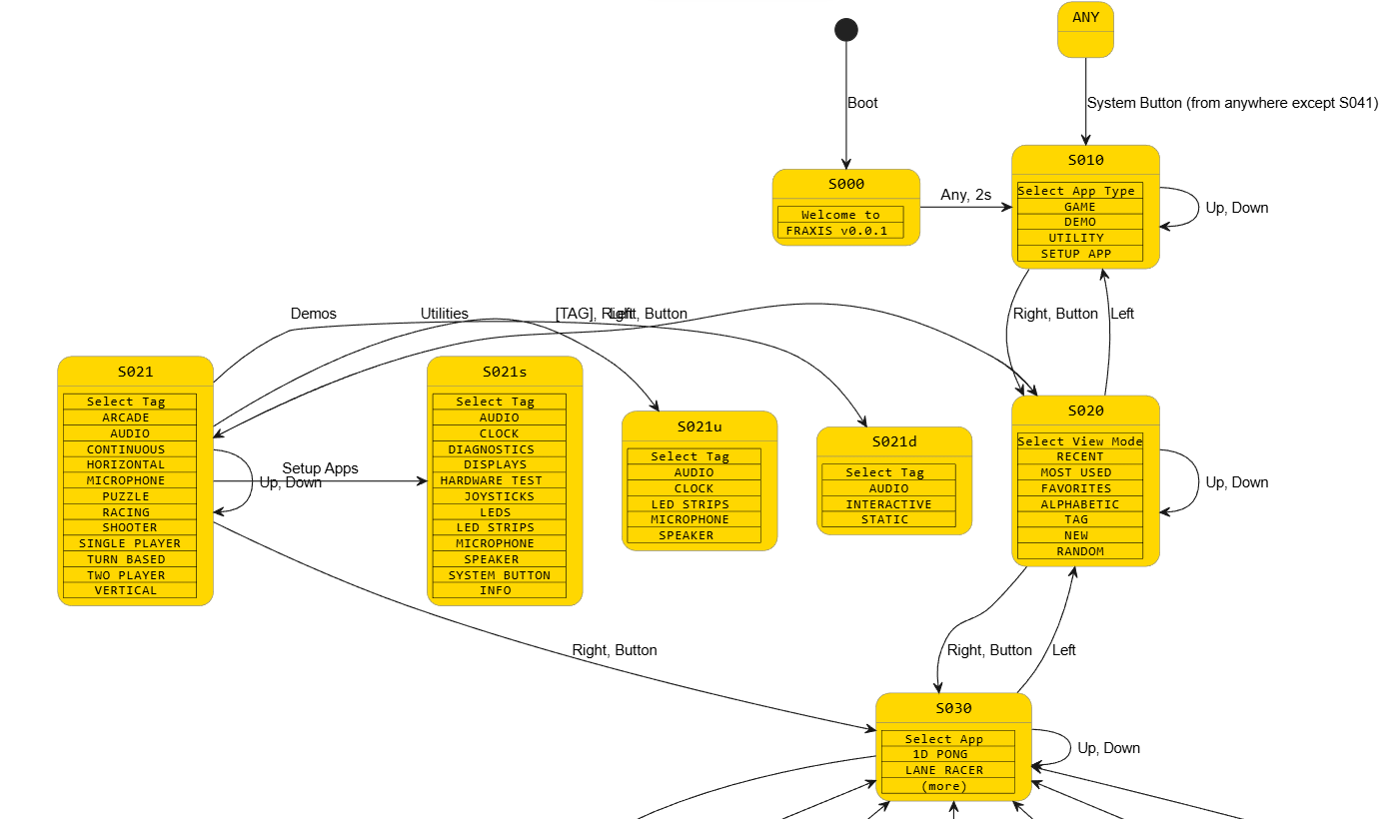
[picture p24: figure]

Screen S000: Welcome

┌────────────────┐

│ Welcome to │
│ FIRAXIS 0.0.1 │
└────────────────┘

After two seconds or a direction/button press, the navigation moves to screen S010.

Screen S01-S010: Select App Type

This screen selects between the application type: Game, Demo, Utility or Setup App.

┌────────────────┐

│Select App Type │
│ GAME │
└────────────────┘

┌────────────────┐

│Select App Type │
│ DEMO │
└────────────────┘

┌────────────────┐

│Select App Type │
│ UTILITY │
└────────────────┘

┌────────────────┐

│Select App Type │
│ SETUP APP │
└────────────────┘

Right/Mouse button press causes the navigation to move to screen S020.

Screen S020: View Modes

Here the view modes to select an app can be set:

View Mode | Description
RECENT | Recently used apps
MOST USED | Apps in order of total execution time
FAVORITES | Apps marked as favorites, in alphabetic order
ALPHABETIC | Apps in alphabetic order
TAG | Apps to be selected by a tag, in alphabetic order
NEW | New apps, which is a fixed list by the developer.
RANDOM | Selects a random game (no further selection is neeeded).

┌────────────────┐

│Select View Mode│
│ RECENT │
└────────────────┘

┌────────────────┐

│Select View Mode│
│ MOST USED │
└────────────────┘

┌────────────────┐

│SELECT VIEW MODE│
│ FAVORITES │
└────────────────┘

┌────────────────┐

│Select View Mode│
│ ALPHABETIC │
└────────────────┘

┌────────────────┐

│Select View Mode│
│ TAG │
└────────────────┘

┌────────────────┐

│Select View Mode│
│ NEW │
└────────────────┘

┌────────────────┐

│Select View Mode│
│ RANDOM │
└────────────────┘

Button/Right: When TAG is selected, navigation moves to screen S021 to select a tag. When RANDOM is selected, a random game is shown and navigation moves to screen S040. In all other cases, screen S030 is shown to select a game from a list.

Screen S021: Select Tag

This screen shows all existing tags for the selected app type.

The following list shows all tags per app type:

Game Tags | Demo Tags | Utility Tags | Setup App Tags
Arcade | Audio | Audio | Audio
Audio | Interactive | Clock | Clock
Continuous | Static | LED Strips | Diagnostics
Horizontal | | Microphone | Displays
Microphone | | Speaker | Hardware Tests
Puzzle | | | Joysticks
Racing | | | LED Strips
Shooter | | | Microphone
Single Player | | | Speaker
Turn Based | | | System Button
Two Player | | | Info
Vertical

Below are a few examples shown:

┌────────────────────┐

│ Select Tag │
│ ^ Evasive │
│ > Shooter │
│ v Single Player │
└────────────────────┘

┌────────────────────┐

│ Select Tag │
│ > Hardware Tests │
└────────────────────┘

After a tag is selected, navigation continues to screen S030.

Screen S030: Select App

In this screen the actual app can be selected. Below are a few examples:

┌────────────────┐

│ Select Game │
│ 1D PONG │
└────────────────┘

┌────────────────┐

│ Select Demo │
│ KNIGHT RIDER │
└────────────────┘

┌────────────────┐

│ Select Utility │
│COUNTDOWN TIMER │
└────────────────┘

┌────────────────┐

│Select Setup App│
│LED STRIPS TEST │
└────────────────┘

### App Execution

This paragraph explains the screens related when an application is running. Typically, the app takes over the joystick control, but the System Button can be used to intervene.

Screen S040: App Start

This screen starts the application.

┌────────────────┐

│ 1D PONG │
│ START │
└────────────────┘

### App Management

These screens can start app an app, make them favorite etc:

- S300: Start (Screen S400)
- S301: Settings (S500)
- S302: Highscores (S520, Games only)
- S303: Reset Highscores (S530, Games only)
- S304: Player Setup (S540, Games only)
- S305: Set as Favorite (S550 or remove from favorites if already a favorite)

┌────────────────┐

│ <Selected App> │
│▬ START ▼│
└────────────────┘

This menu assume that Game 1D Pong has been selected.

┌────────────────┐

│ 1D Pong │
│▲ START ▼│
└────────────────┘

┌────────────────┐

│ 1D Pong │
│▲ SETTINGS ▼│
└────────────────┘

┌────────────────┐

│ 1D Pong │
│▲ HIGH SCORES ▼│
└────────────────┘

┌────────────────┐

│ 1D Pong │
│▲ PLAYER SETUP ▼│
└────────────────┘

┌────────────────┐

│ 1D Pong │
│▲ SET AS FAV. ▼│
└────────────────┘

┌────────────────┐

│ 1D Pong │
│▲REMOVE AS FAV.▼│
└────────────────┘

# Games

## Introduction

In the games some common terms are used:

- Home: the LED closest to the player (both players have their own home).
- Home distance: The distance between some object and the home of the player.
- Center: The central LED, although due there are an even number, it is considered the middle LED closest to one player.
- Player 1: Bottom side player
- Player 2: Top side player
- Central Panel: Central control panel

## Tags

Games are categorized by various tags, and a game can be part of multiple categories.

Below the games are shown including tags.

## List of Games

Game Player Count Genre Game Type

1D Endless Runner

1D Pong

1D Snake

Dual Line Dodge

Lane Shooter 1 or 2 Shooter 4 Rows

Quadrows Breakout

Quadrows Endless Runner

Quadrows Pong 2 Pong 4 Rows

Quadrows Snake

Reaction Speed

Simon Memory

Tug of Light

Player Count: One Player / Two Player / One or Two Players

Genre: Shooter, Pong, Racer, Snake, Reaction, Rhythm, Puzzle, Endless, Platformer,

Arena, Dodge, Tug Of War, Breakout

Game Type: 1D, 4 Rows

# Demos

## Introduction

## Tags

## List of Demos

## LED Wave Demo

## Color Patterns

### Description

This is not a game, but a demo of color patterns.

Knight rider

Galaxy

Fire

Stroboscope

Rainbow

Interaction via joystick

### UI

### Controls

### Scoring

### Settings

# Utilities

## Introduction

## List of Utilities

## Draw

### Description

This is not a game, but a drawing program. With the pot meter a LED can be selected, and with the up/down keys the color can be changed. The select button switches the LED on or off.

### UI

### Controls

### Scoring

### Settings

## CLOCK

64 LEDs, e.g 12:34:56

2 LEDs 1: 0-2

1 LED gap

5 LEDs 3: 0-5

1 LED gap

10 LEDs 4: 0-9

1 LED gap

5 LEDs 3: 0-5

1 LED gap

10 LEDs 4: 0-9

Total 35 LEDs

Even LEDs red. Uneven reds blue. Fifth green to make visibility better.

Possibly keeping hhmmss led positions constant.

Think about date.

## ALARM

ime and or date alarm., or countdown

Input via LCD, alarm via led colors and LCD.

## STop watch

# System

## LED Strips Test (+Brightness Control)

## LED Segments Test (+Brightness Control)

## LCD Display Tests (+Brightness Control)

## Joysticks Test (+Calibration)

## Audio Test (+Volume Set)

## OTA Software Update

# Setup Applications

## Introduction

## List of Setup Applications

# Software Architecture

## Introduction

## SRAM Memory Usage

Item | Bytes
LED Strips | 64
Settings | 16
Generic variables | 64
Stack space | 80
Total | 224
Available | 2,048
Remaining | 1,824
Remaining % | 89.06%

## Flash Memory Usage

Item | Bytes per item | #Items | Total
Settings | 16 | 32 | 512
Version | 10 | 1 | 10
Total | | | 522
Available | | | 1,024
Remaining | | | 502
Remaining % | | | 49.02%

## Flash Memory Usage

Item | Bytes per item | #Items | Total
I/O Functionality | 1024 | 1 | 1,024
UI Functionality | 1536 | 1 | 1,536.0
Game Code | 900 | 32 | 28,800.0
Total | | | 31,360
Available | | | 32,256
Remaining | | | 896
Remaining % | | | 2.78%

# Appendix A: Games

## Endless Runner

A single‑strip runner where obstacles scroll toward you and you survive by reacting quickly.

(Has a richer 4‑row counterpart → Quadrows Runner)1D Mines

A Minesweeper‑style puzzle on one LED strip where you reveal safe spots and avoid hidden mines.

(The 4‑row version becomes a different game → Quadrows Mines)

## 1D Snake

Classic Snake on a single LED strip, growing longer as you collect food.

(The 4‑row version is a different game → Quadrows Snake)

## 1D Sprint

A fast single‑strip reaction game where obstacles appear and you must dodge or jump with precise timing.

(No meaningful 4‑row version)

## Center Clash

Two players fire projectiles toward the center; timing determines whether shots collide or pass through.

(No meaningful 4‑row version)

## Color Catch

Colored pixels fall down the rows; you must catch only the correct color while avoiding the wrong ones.

(1D and 4‑row versions feel identical → same game with settings)

## Dual Dash

A two‑player race from top to bottom, dodging obstacles and trying to reach the finish first.

(Only makes sense in 4 rows)

## Dual Defender

Each player defends their side from incoming waves of enemies or projectiles.

(Only makes sense in 4 rows)

## Dual Snake Battle

Two snakes compete for food and try to force each other into collisions.

(Only makes sense in 4 rows)

## Lane Racer

A forward‑scrolling racing game where obstacles appear in lanes and you switch lanes to avoid them.

## Lane Shooter

Targets or enemies move along the rows while you shoot vertically to clear them.

## Light Harvest

Collect moving light orbs while avoiding harmful ones as they travel across the rows.

## Light Memory

A Simon‑style memory game where sequences of lights appear across the rows and must be repeated.

## Light Runner

A fast lane‑switching endless runner where obstacles appear in random lanes and you must react quickly to survive.

(This is the Quadrows Runner version of 1D Endless Runner)

## Meteor Sweep

Meteors fall from the right side; you shoot them before they reach the left.

## Mirror Clash

Players control reflective paddles that bounce shots back and forth until someone gets hit.

(Only meaningful in 4 rows)

## Pixel Drift

A lane‑switching drift game where you avoid walls and collect boosts while sliding between lanes.

## Pixel Storm

A simplified bullet‑hell game with patterns of projectiles moving across the rows.

## Pixel Tennis

A chaotic Pong‑like game where the ball can jump between lanes, making rallies unpredictable.

(Only meaningful in 4 rows)

## Pong

Speed changes when hitting close enough (fast when good, slow when bad)

## Pulse Arena

Waves of light pulses move toward the player; some must be dodged, others blocked depending on color.

(Only meaningful in 4 rows)

## RGB Chaser

Colored blocks fall down, by selecting the right row you can shoot the right color block to stop a same color

e.g. up = Red, button = Green, bottom = Blue

https://www.youtube.com/shorts/XopU0OKFKks

## Quadrows Breakout

A Breakout‑style game where a bouncing ball destroys blocks arranged across four LED rows.

(The 1D version is a different game → 1D Breakout if you ever add it)

## Quadrows Labyrinth

A scrolling maze where you must choose the correct lane to avoid dead ends and survive.

(The 1D version is a different game → 1D Labyrinth)

## Quadrows Mines

A scrolling minefield across four rows where you must navigate safely.

(The 1D version is a different game → 1D Mines)

## Quadrows Pong

A lane‑switching version of Pong where the ball can travel across all four rows, adding chaos and strategy.

(The 1D version is classic Pong → different game)

### Description

Classic Pong but with lane switching. Each player controls a paddle that can move left/right and switch between the 4 rows.

### Game Rules

The ball starts from the center to a random home.

The player can press the button to switch the ball around in the direction of the other player.

The button only responds when the ball is on that player’s side.

A ball moves from the center towards a random home.

The player from that home has to press a button when the ball is as close as possible to its home position. When the button is not pressed at reaching the home position, points will be subtracted.

The ball switches direction anyway and the speed of the ball is increased.

Initially the speed is 50 ms per position (thus a full length of the strip takes 144 * 50 ms = 7.2 seconds. Every reversal the speed increases with a percentage, by default 2%

### Scoring

The player scores points when the ball is reversed close to the player’s home position, by default:

at home: 100 points

1 position away from home: 50 points

2 positions away from home: 25 points

3 positions away from home: 10 points

4 positions away from home: 5 points

5 positions away from home: 3 points

6 positions away from home: 1 point

When the button is not pressed before the ball reaches the home position and would go one position further, points are subtracted. By default this is 100 points.

### UI

The ball color is red.

The game time is only used when the win condition setting is set to Time Limit.

The score displays show the score of each player.

### Controls

Any button can be used to hit the ball.

### Settings

Item | Unit | Range | Step | Bytes
Player Mode | choice | Single Player, Two Players | 1 | 1
Win Condition | choice | Misses, Time Limit | 1 | 1
Number of Misses | amount | 0-16 | 1 | 1
Time Limit | s | 30-300 | 10 | 1
Home button press score | points | 0-100 | 10 | 1
Home distance 1 score | points | 0-100 | 10 | 1
Home distance 2 score | points | 0-100 | 10 | 1
Home distance 3 score | points | 0-100 | 10 | 1
Initial speed | ms | 100-1,700 | 100 | 1
Speed increase | ms | 0-15 | 1 | 1
Total (bytes) | | | | 10

## Quadrows Snake

### Tags

Player Count: 2, Genre: Pong, Game Type: 4 Rows

## Description

Snake can move between lanes. Two‑player mode allows competitive or cooperative play.

## Simon Memory

### Description

Remember LEDs. Every successful round one LED more to remember. Use pot to go to approximate location and press ok.

Get more points when closer to LED to remember.

### UI

### Controls

### Scoring

### Settings

## Quadrows Rhythm

Notes fall down the lanes in sync with sound effects; you hit buttons in rhythm.

(The 1D version is a different game → 1D Rhythm)

## Quadrows Snake

A multi‑lane Snake variant where the snake can switch between rows and compete or cooperate.

(The 1D version is classic Snake → different game)

## Tug of Light

A tug‑of‑war game where both players mash their button to pull a glowing pixel toward their side.

(Only meaningful in 1D)

# Appendix B: Demos

# Appendix C: Utilities

# Appendix D: Setup Applications

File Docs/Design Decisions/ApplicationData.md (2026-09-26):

# Application Data

## See also

See PermanentStorage.md for a detailed description how the above data is stored.

## Applications

There will be many applications on the system.

The last executed application is stored to the user can easily select/sort by it.
The amount of executions per application is stored so the user can easily select/sort by it.

## Menu Application

The menu is a special application that is active from the start and has application number 0.
It can launch or pause another application, and when that application stops or pauses, execution is
returned to the Menu application.

## Versions

An application can have multiple versions (upto 256, but typically 1 or a few).

## Application Type

Applications are divided in four categories:

- Games: games of all kind.
- Demoes: interactive or non-interactive demoes showing the capabilities of the device.
- Tools: useful apps for the user, such as a clock, countdown alarm etc.
- Utilities: apps used for setup, diagnosing, measuring and debugging the system.

## Tags

Each application has (multiple) tags, and tags are hardcoded in the application.
Some tags are specific to certain application types.

Tags are used to filter the applications for easy selection by the user.

## Presets

Each application has presets. A preset has a name and contains a set of 'settings'.

The last selected preset for each application is stored, so the user can easily select the last executed preset.

## Settings

Each preset has settings which are specific for a game, or even game version.
Settings can be e.g. HitPoints, Ball Speed, Number of Obstacles etc.

## Highscores

Only for games, high scores are kept, containing of a name of the player and the score.

## Storage

See PermanentStorage.md for a detailed description how the above data is stored.

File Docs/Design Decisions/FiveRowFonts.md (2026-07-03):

```
0        10         20       30        40        50        60        70
012345678901234567890123456789012345678901234567890123456789012345678901

█   █ ███  ███  █   █ ████ █     █   █ ████ ███ ████ ███ ████ ████   ███
██ ██  █  █   █ █   █ █    █     █ ██  █     █     █   █ █    █   █ █
█ █ █  █  █     █████ ████ █     ██    ████  █     █  █  ████ ████   ██
█   █  █  █   █ █   █ █    █     █ ██  █     █  █  █ █   █    █   █    █
█   █ ███  ███  █   █ ████ ███   █   █ ████ ███  ██  ███ ████ █   █ ███

0        10         20       30        40        50        60        70
012345678901234567890123456789012345678901234567890123456789012345678901

█   █ ███ █   █ ████     ████  ███  █   █ ████   ███  █   █ ████ █   █
██ ██  █  █ ██  █       █     █   █ █   █ █   █ █   █ █   █ █    ██  █
█ █ █  █  ██    ███      ███  █     █████ ████  █████ █   █ ████ █ █ █
█   █  █  █ ██  █           █ █   █ █   █ █   █ █   █  █ █  █    █  ██
█   █ ███ █   █ ████    ████   ███  █   █ █   █ █   █   █   ████ █   █

0        10         20       30        40        50        60        70
012345678901234567890123456789012345678901234567890123456789012345678901

█    ██  ███  ███ █ █ █ █ ████ █  █   ███  ███  █  █  ███
█   █  █ █  █ █   █ █ █ █    █ █ █    █  █ █  █ █  █ █
█   █  █ █  █ ███ █ █ █ █    █ ██     ███  ███  █  █  ██
█   █  █ █  █ █   █ █ █ █ █  █ █ █    █  █ █  █ █  █    █
███  ██  ███  ███  █ █  █  ██  █  █   ███  █  █  ██  ███

█     ███  ████  ████ █ █ █ ███ ████ █   █    ████  ████  █   █  ████
█    █   █ █   █ █    █ █ █  █     █ █ ██     █   █ █   █ █   █ █
█    █   █ █   █ ███  █ █ █  █     █ ██       ████  ████  █   █  ███
█    █   █ █   █ █    █ █ █  █  █  █ █ ██     █   █ █   █ █   █     █
████  ███  ████  ████  █ █  ███  ██  █   █    ████  █   █  ███  ████

0        10         20       30        40        50        60        70
012345678901234567890123456789012345678901234567890123456789012345678901

███   ██  ███    █   █  ██  █   █   ███ ███  ███
█  █ █  █ █  █   █   █ █  █ ██  █   █   █  █ █  █
███  █  █ ███    █   █ ████ █ █ █   ███ ███  ███
█  █ █  █ █  █    █ █  █  █ █  ██   █   █  █ █
█  █  ██  ███      █   █  █ █   █   ███ █  █ █

████   ███  ████     █   █  ███  █   █    ████ ████  ████
█   █ █   █ █   █    █   █ █   █ ██  █    █    █   █ █   █
████  █   █ ████     █   █ █████ █ █ █    ███  ████  ████
█   █ █   █ █   █     █ █  █   █ █  ██    █    █   █ █
█   █  ███  ████       █   █   █ █   █    ████ █   █ █

0        10         20       30        40        50        60        70
012345678901234567890123456789012345678901234567890123456789012345678901

 ███   ██  █  █ ███     ███  █ ███  ██  █  █  ██  █   █  ███
█     █  █ █  █ █  █   █     █  █  █  █ █  █ █  █ ██  █ █
 ███  ████ █  █ ███     ███  █  █  █  █ ████ ████ █ █ █ █ ██
    █ █  █ █  █ █  █       █ █  █  █  █ █  █ █  █ █  ██ █  █
 ███  █  █  ██  █  █    ███  █  █   ██  █  █ █  █ █   █  ██

 ██  █  █ █ ██  █  █ ██   █     ██ █ ███  █  █ █  █  ██   ███
█   █ █ █ █ █ █ █  █ █ █ █ █   █   █  █  █ █ █ █ █ █ █ █ █
 █  ███ █ █ ██  █  █ █ █ ███    █  █  █  █ █ ███ ███ █ █ █ ██
  █ █ █ █ █ █ █ █  █ █ █ █ █     █ █  █  █ █ █ █ █ █ █ █ █  █
██  █ █  █  █ █ ██ █ █ █ █ █   ██  █  █   █  █ █ █ █ █ █  ██

 ██  ██  █ █ ██  █  █ ██   ██     ██ █ ███  █  █ █  ██  ██   ███
█   █  █ █ █ █ █ █  █ █ █ █  █   █   █  █  █ █ █ █ █  █ █ █ █
 █  ████ █ █ ██  █  █ █ █ ████    █  █  █  █ █ ███ ████ █ █ █ ██
  █ █  █ █ █ █ █ █  █ █ █ █  █     █ █  █  █ █ █ █ █  █ █ █ █  █
██  █  █  █  █ █ ██ █ █ █ █  █   ██  █  █   █  █ █ █  █ █ █  ██

 ███  ██  █ █ ██  █  █ ██   ██     ███ █ ███  █  █ █  ██  ██   ███
█    █  █ █ █ █ █ █  █ █ █ █  █   █    █  █  █ █ █ █ █  █ █ █ █
 ██  ████ █ █ ██  █  █ █ █ ████    ██  █  █  █ █ ███ ████ █ █ █ ██
   █ █  █ █ █ █ █ █  █ █ █ █  █      █ █  █  █ █ █ █ █  █ █ █ █  █
███  █  █  █  █ █ ██ █ █ █ █  █   ███  █  █   █  █ █ █  █ █ █  ██

 ███  ██  █  █ ██  █   █ ███   ██    ███ █ ███  █  █  █  ██  ███   ███
█    █  █ █  █ █ █ █   █ █  █ █  █  █    █  █  █ █ █  █ █  █ █  █ █
 ██  ████ █  █ ██  █   █ █  █ ████   ██  █  █  █ █ ████ ████ █  █ █ ██
   █ █  █ █  █ █ █ █   █ █  █ █  █     █ █  █  █ █ █  █ █  █ █  █ █  █
███  █  █  ██  █ █ ███ █ █  █ █  █  ███  █  █   █  █  █ █  █ █  █  ██

 ███  ██  █  █ ███  █   ███ █  █  ██     ███ ███ ███  ██  █  █  ██  █   █  ███
█    █  █ █  █ █  █ █    █  ██ █ █  █   █     █   █  █  █ █  █ █  █ ██  █ █
 ██  ████ █  █ ███  █    █  █ ██ ████    ██   █   █  █  █ ████ ████ █ █ █ █ ██
   █ █  █ █  █ █  █ █    █  █ ██ █  █      █  █   █  █  █ █  █ █  █ █  ██ █  █
███  █  █  ██  █  █ ███ ███ █  █ █  █   ███  ███  █   ██  █  █ █  █ █   █  ██

012345678901234567890123456789012345678901234567890123456789012345678901
0        10         20       30        40        50        60        70

██   █   █   ██  █ █  █  ██   ██  ███ ██    ██   █   █  █
█ █ █ █ █ █ █    █ █ █ █ █ █  █ █ █   █ █   █ █ █ █ █ █ █
██  █ █ █ █  █   █ █ ███ █ █  █ █ ███ ██    ██  █ █ █ █ █
█ █ █ █ █ █   █   █  █ █ █ █  █ █ █   █ █   █   █ █ █ █ █
█ █  █   █  ██    █  █ █ █ █  ██  ███ █ █   █    █ █ █  ███

███   ██   ██   ██  █   █  ██  ███   ███  ███ ███    ███   ██   ██  █
█  █ █  █ █  █ █    █   █ █  █ █  █  █  █ █   █  █   █  █ █  █ █  █ █
███  █  █ █  █  █   █   █ ████ █  █  █  █ ███ ███    ███  █  █ █  █ █
█  █ █  █ █  █   █   █ █  █  █ █  █  █ █  █   █  █   █    █  █ █  █ █
█  █  ██   █   ██     █   █  █ █  █  ███  ███ █  █   █     ██   ██  ████

A  3  3c   4   4c     5   5b               5c   5cb         a 3  3b           4
   █  ███  ██  ████  ███   ██   ██   ███  █████ ████ ████     █  ██  ███ ███
  █ █ █ █ █  █ █  █ █   █ █ ██ ██ █ ██ ██ █   █ █ ██ ██ █      █   █   █   █
  ███ ███ ████ ████ █████ ████ ████ █████ █████ ████ ████     ██  ██ ███ ███
  █ █ █ █ █  █ █  █ █   █ █ ██ ██ █ ██ ██ █   █ █ ██ ██ █    █ █ █ █ █ █ █ █
  █ █ █ █ █  █ █  █ █   █ █ ██ ██ █ ██ ██ █   █ █ ██ ██ █     ██  ██  ██ ███

B 3   4    4b2        5     5b                  b 3   3c   4    4b          5
  ██  ███  ███  ███  ████  ████  ████  ████      █   █    █    ██    █    ██
  █ █ █  █ █ ██ ██ █ █   █ ██  █ █  ██ ██ ██     █   █    █    ██    █    ██
  ██  ███  ███  ███  ████  ████  ████  ████      ██  ███  ███  ███   ███  ████
  █ █ █  █ █ ██ ██ █ █   █ ██  █ █  ██ ██ ██     █ █ █ █  █  █ ██ █  █ ██ ██ ██
  ██  ███  ███  ███  ████  ████  ████  ████      ██  ███  ███  ███   ███  ████

C  2  3  3b       4         4b
   █  ██  ██  ██  ██   ███  ██
  █  █   ██  ██  █  █ █    ████
  █  █   █   ██  █    █    █
  █  █   ██  ██  █  █ █    ████
   █  ██  ██  ██  ██   ███  ██

012345678901234567890123456789012345678901234567890123456789012345678901
0        10         20       30        40        50        60        70

Memory needed:
chars: 250 different chars (cap/small/symbols) * 10 variations * 5 bytes/char = 12.5KB Flash

```

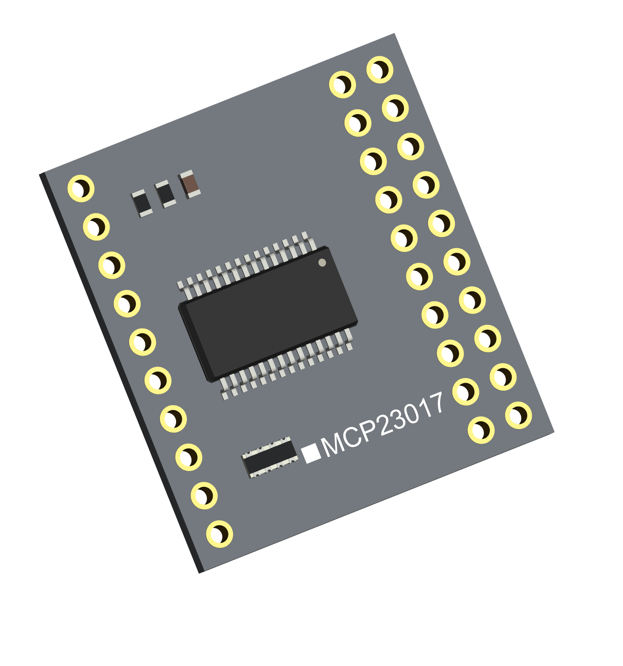
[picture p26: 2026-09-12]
Hardware/Grabcad/Mcp23017 module/mcp23017_recto.png

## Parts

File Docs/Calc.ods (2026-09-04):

Enclosure
Ribs
Bouwhout ruw vuren 10x38 mm lengte 330 cm kopen? Vuren ruw | Karwei (https://www.karwei.nl/assortiment/bouwhout-ruw-vuren-10x38-mm-lengte-330-cm/p/B498344)
Over lengte doorzagen met cirkelzaag, geen geleiderail nodig
Lat 1
 |  |  |  |  |  | Total | Main box length |  | Bridge |  | Bridge |  | Bridge |  | Bridge |  | Bridge |  | Bridge |  | Speaker Box | Speaker Box
 | Length | Amount/Element | Amount | Total | Length (cm) | 256 | 52 | 52 | 18 | 6 | 18 | 6 | 18 | 6 | 18 | 6 | 18 | 6 | 18 | 6 | 4 | 4
Main box length ribs | 52 | 1 | 2 | 104 | Height: (below, mm, 38mm)
Main box height | 8 | 1 | 4 | 32 | 1 |  | One side | One side | Length 18 cm | Vertical parts | Length 18 cm | Vertical parts | Length 18 cm | Vertical parts | Length 18 cm | Vertical parts | Length 18 cm | Vertical parts | Length 18 cm | Vertical parts | Top left | Top left
Bridge Horizontal | 16 | 2 | 6 | 192 | 1 |  | x | x | x | x | x | x | x | x | x | x | x | x | x | x | Top right | Top right
Bridge Vertical | 6 | 2 | 6 | 72 | 1 |  | x | x | x | x | x | x | x | x | x | x | x | x | x | x | Bottom left | Bottom left
Speaker box | 4 | 12 | 1 | 48 | 1 |  | x | x | x | x | x | x | x | x | x | x | x | x | x | x | Bottom right | Bottom right
Speaker box 2 | 2 | 12 | 1 | 24
 |  |  |  | 0
 |  |  |  | 0
Total |  |  |  | 472
montage:
- 3mm 16mm (in bezit)
- washers m5, 15mm (min 12mm breedte nodig voor mdf), aliexpres, 2 + 3 euro
Voorboren 2.5mm, stoppen zodra mdf raakt

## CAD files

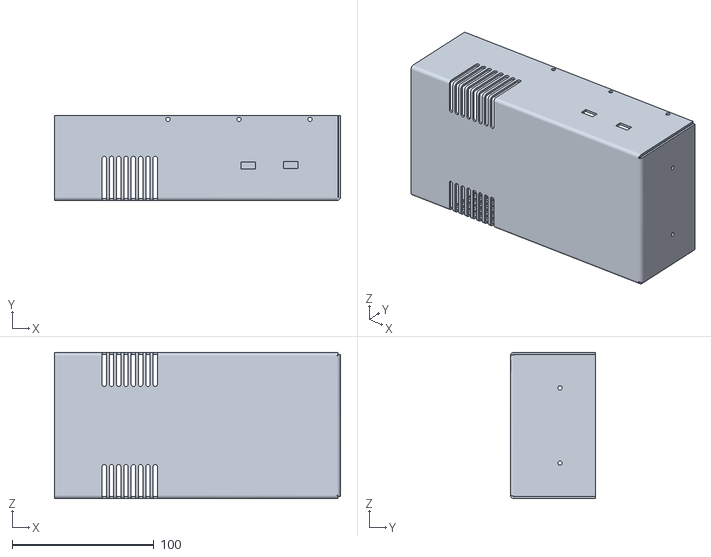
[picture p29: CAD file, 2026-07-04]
Hardware/Tinkercad/Power supply/Casing PSU Assembly - Muhammad Yanuardi Irfani - Casing PSU 2 - Muhammad Yanuardi Irfani-1.STL
201.5 x 60.0 x 103.0

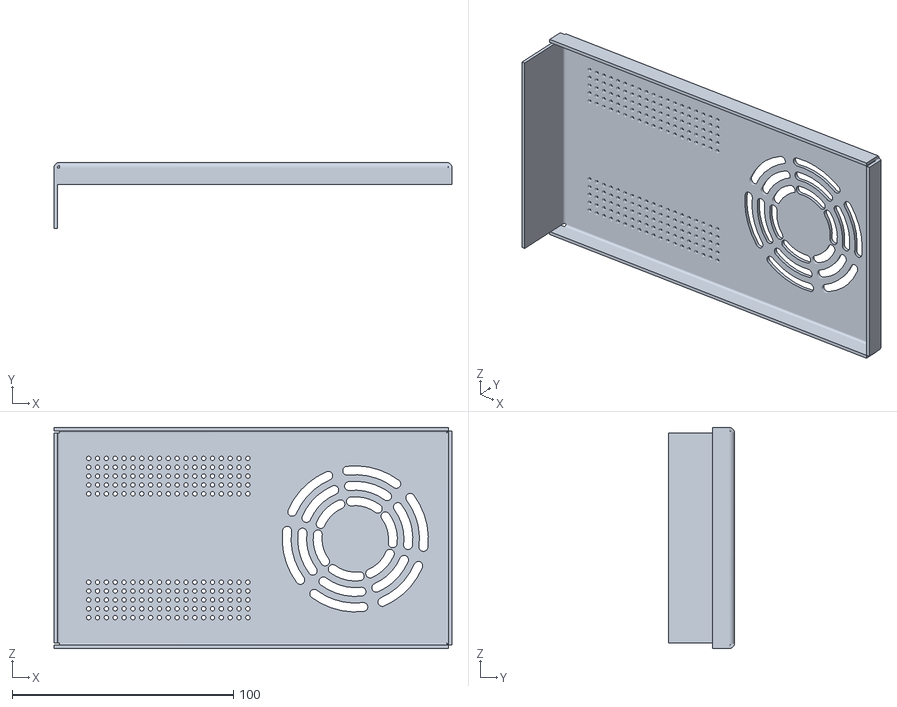
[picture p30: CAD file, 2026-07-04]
Hardware/Tinkercad/Power supply/Casing PSU Assembly - Muhammad Yanuardi Irfani - Casing PSU 1 - Muhammad Yanuardi Irfani-3.STL
180.0 x 30.0 x 100.0

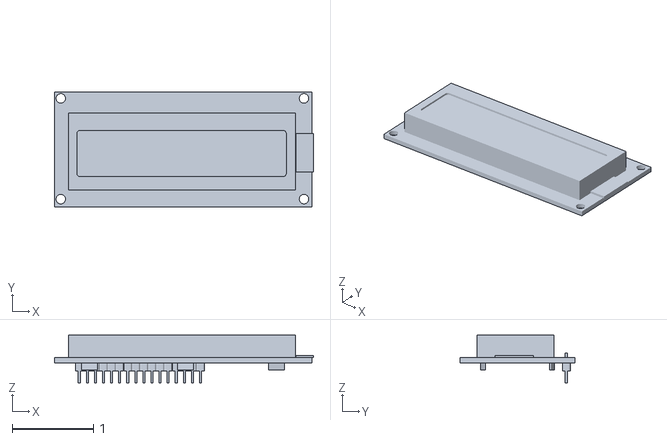
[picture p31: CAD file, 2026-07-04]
Hardware/Tinkercad/1602/1602_lcd.stl
3.19 x 1.42 x 0.59

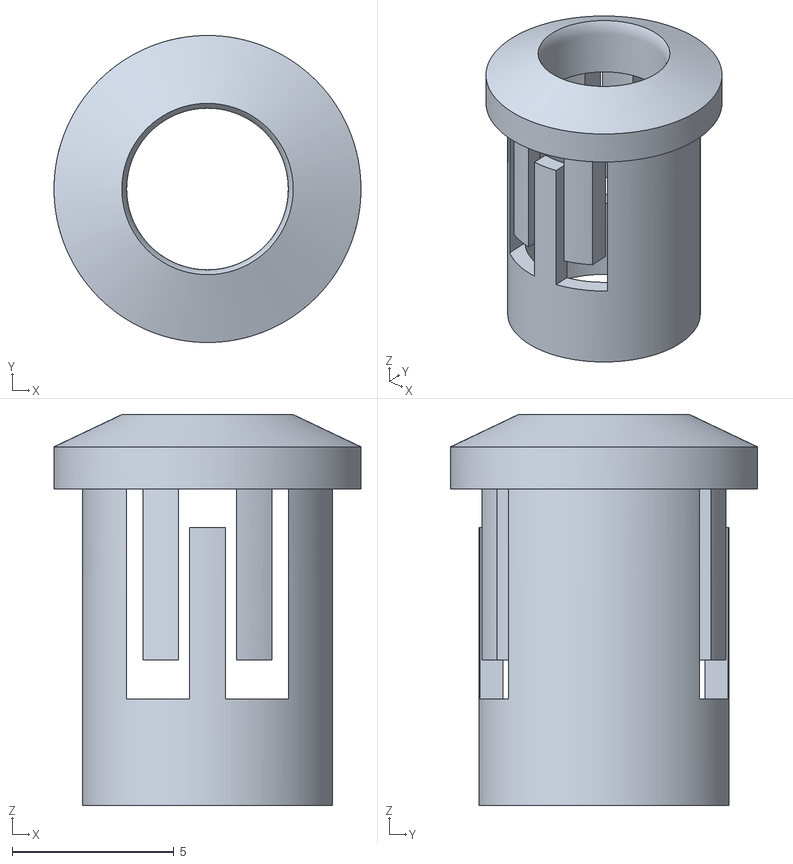
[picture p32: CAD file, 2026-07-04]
Hardware/Tinkercad/3mm Led holder/files/LED5mmHolder.stl
9.50 x 9.50 x 12.1

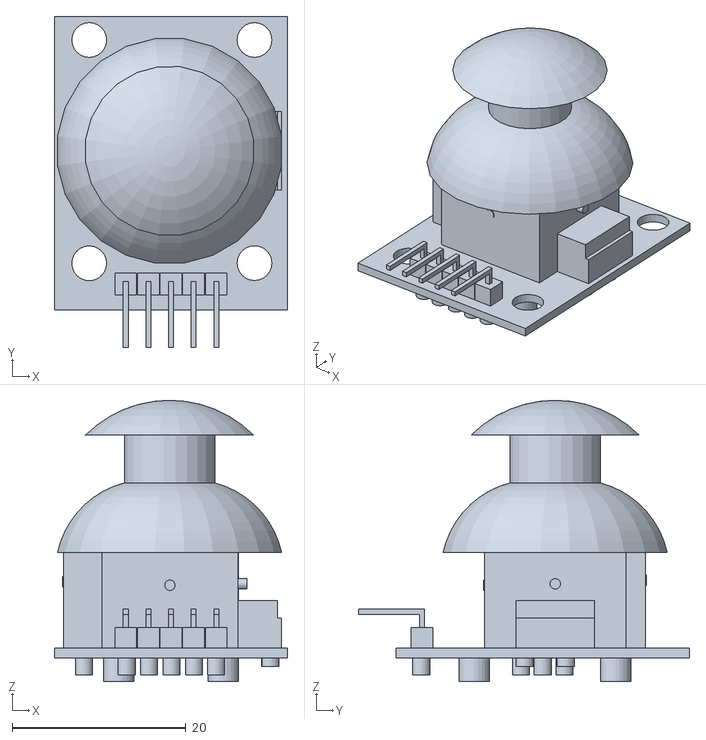
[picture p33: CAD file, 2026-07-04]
Hardware/Tinkercad/Arduino Joystick/files/PS2_Jostick_for_Arduino.stl
26.8 x 38.0 x 32.3

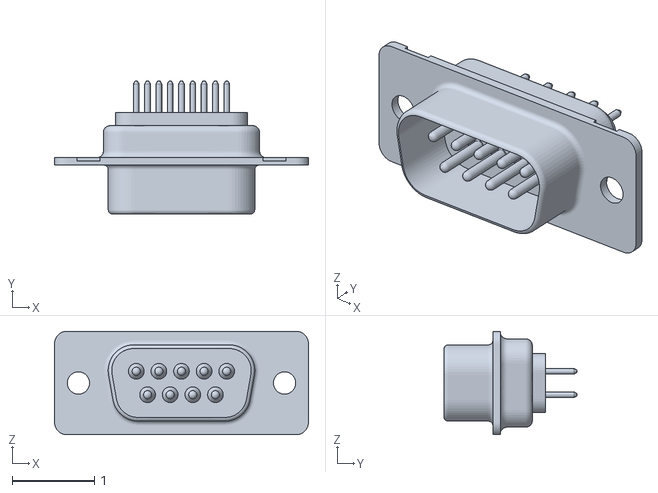
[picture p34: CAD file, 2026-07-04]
Hardware/Tinkercad/DB9/plug_DB9.stl
3.08 x 1.61 x 1.25

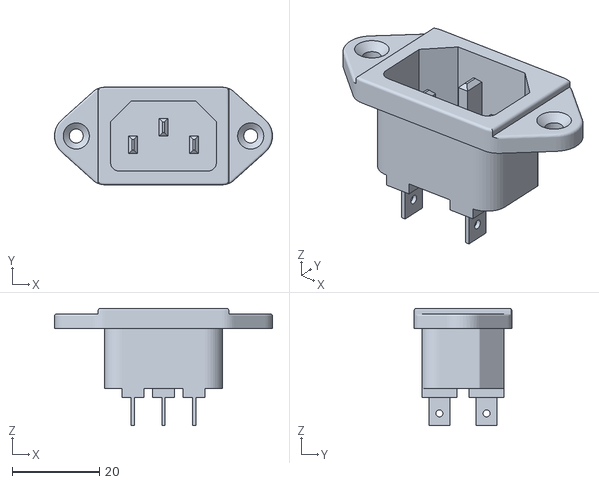
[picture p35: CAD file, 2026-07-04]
Hardware/Tinkercad/IEC320 Power plug/IEC320 3P AC 250V male socket.STL
50.0 x 22.4 x 26.9

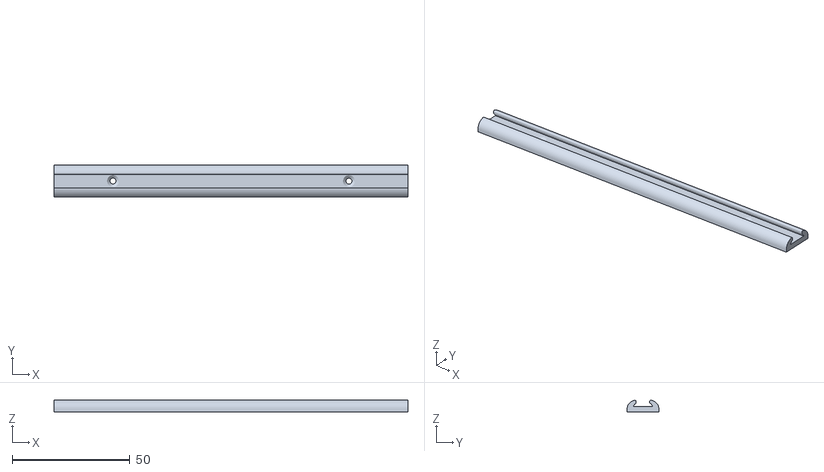
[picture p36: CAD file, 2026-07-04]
Hardware/Tinkercad/Led strip holder/GregorB-LIghtStrip_Holder-8mmStrip_lenght150mm.stl
150.0 x 13.5 x 4.93

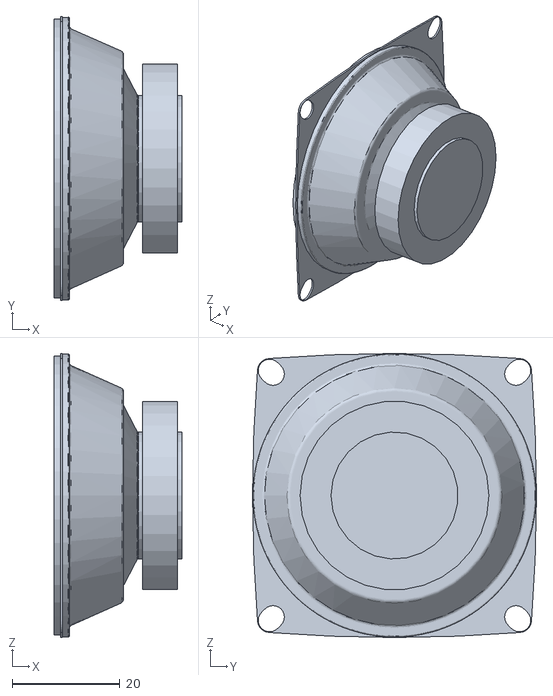
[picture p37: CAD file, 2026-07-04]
Hardware/Tinkercad/Speaker 3D/Speaker.stl
23.6 x 52.6 x 52.6

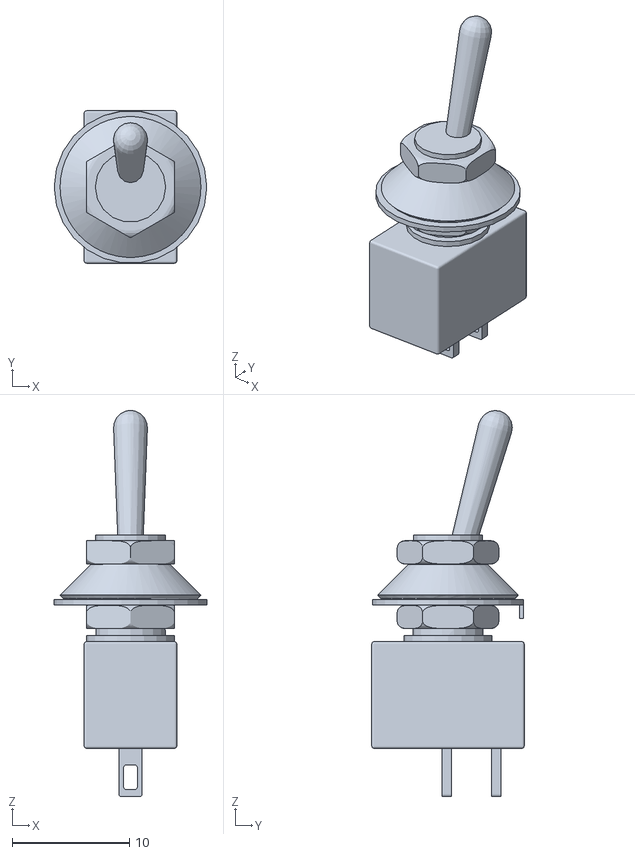
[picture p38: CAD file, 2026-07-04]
Hardware/Tinkercad/Toggle Switch/mini toggle switch spst.stl
13.0 x 13.0 x 32.9

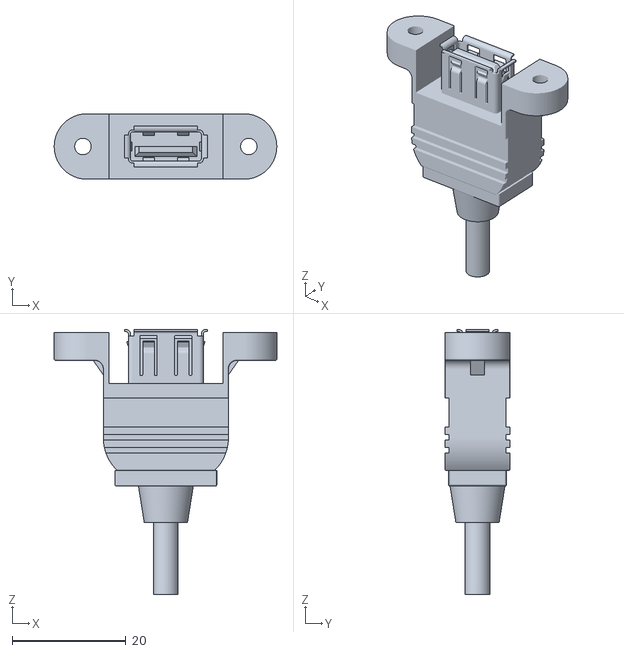
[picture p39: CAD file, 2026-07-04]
Hardware/Tinkercad/USB Panel Mount/USB Type A - panel mount.STL
39.1 x 11.5 x 46.6

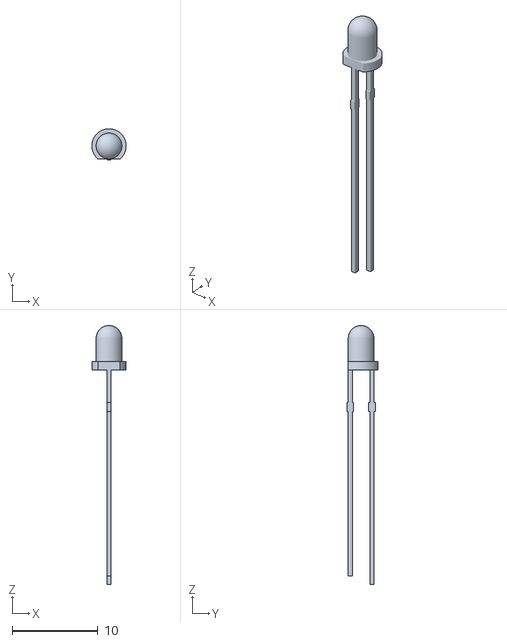
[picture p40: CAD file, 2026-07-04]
Hardware/Tinkercad/3mm Led holder/files/LED3mm.stl
4.00 x 3.67 x 30.2

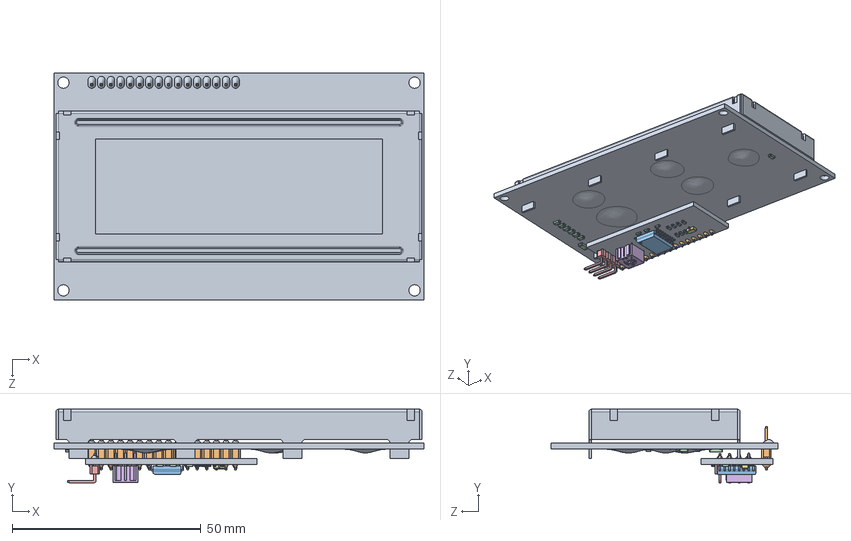
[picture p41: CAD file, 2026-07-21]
Hardware/Grabcad/2004 display/LCD2004 IIC_I2C, 20x4 - Sestava.SLDASM
98.0 x 19.5 x 60.0 mm
LCD2004 IIC_I2C, 20x4
Kolíková lišta přímá krátká - 2,54mm
SO16W
SMD rezistory x 18
Kolíková lišta úhlová R2 krátká - 2,54mm
TRIMR - 10K, BOURNS 3362P-103LF
SOT23-3

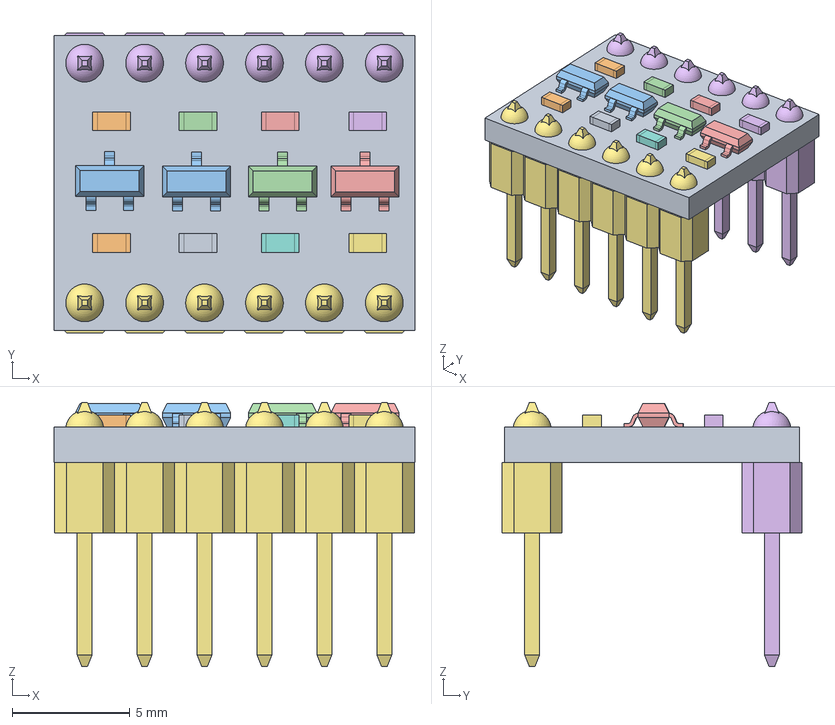
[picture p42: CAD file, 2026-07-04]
Hardware/Grabcad/Logic Level Converter/Logic Level Converter/Logic Level Converter Assembly.FCStd
15.3 x 12.7 x 11.2 mm
Board_001
0603 Resistor_001
Surface Mount Transistor_001
0603 Resistor_002
0603 Resistor_003
0603 Resistor_004
0603 Resistor_005
0603 Resistor_006
0603 Resistor_007
0603 Resistor_008
Surface Mount Transistor_002
Surface Mount Transistor_003
Surface Mount Transistor_004
1x6 Male Header_001
1x6 Male Header_002

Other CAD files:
Hardware/Grabcad/Buzzer Module - FC-07/Buzzer Module - FC-07.SLDASM
Hardware/Grabcad/1506 led lighting profile 1 ledstrip cover/1506_light_profile.stp
Hardware/Grabcad/Arduino Joystick Module/Arduino Joystick Module .stp
Hardware/Grabcad/BOB-12009/BOB-12009.step
Hardware/Grabcad/2004 display/Kolíková lišta přímá krátká - 2,54mm.SLDPRT
Hardware/Grabcad/2004 display/Kolíková lišta úhlová R2 krátká - 2,54mm.SLDPRT
Hardware/Grabcad/2004 display/LCD2004 IIC_I2C, 20x4.SLDPRT
Hardware/Grabcad/2004 display/SMD rezistory.SLDPRT
Hardware/Grabcad/2004 display/SO16W.SLDPRT
Hardware/Grabcad/2004 display/SOT23-3.SLDPRT
Hardware/Grabcad/2004 display/TRIMR - 10K, BOURNS 3362P-103LF.SLDPRT
Hardware/Grabcad/Buzzer Module - FC-07/Buzzer - 7.6mm.SLDPRT
Hardware/Grabcad/Buzzer Module - FC-07/Buzzer Module - FC-07 - PCB.SLDPRT
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

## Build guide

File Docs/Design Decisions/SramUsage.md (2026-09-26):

# SRAM usage

## Components

Below is a list for SRAM usage

- 4 KB, Metadata file from Micro SD
- 15-20 KB, RTOS framework
- 10-50 KB for RTOS tasks
- 3 KB, led strip buffers, 5x72 leds, double buffer
- 1-2 KB, NVS support
- 1 KB, SPI support
- 1 KB, I2C support, with mcp23017 and 2004 LCD display
- 0.5 KB, tm1637
- 4-8 KB, micro SD support
- 4-8 KB, I2S buffers, 16 bit, 16 kHz, mono for inmp1441 microphone and MAX53987 amp
  50-80 KB, WiFi support
- 40-50 KB, Bluetooth support for keyboard

## Conclusion

- Around 250 KB SRAM needed
- No PSRAM needed

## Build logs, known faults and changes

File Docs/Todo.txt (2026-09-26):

sep wk 1: applications
sep wk 2: breadboard test mcp + ic, joystick, leds, button,interrupt
          led strips, tm1637
sep wk 3: software stack with hardware
sep wk 4: breakboard test:  i2s speaker, i2s microphone (buzzer) 
          breakdboard test: sd card

oct wk 1: calculate wood/mdf + saw + paint
oct wk 2: soldering + wiring
oct wk 3: soldering + wiring
oct wk 4: 

nov wk 1: 

SOON:

- Add ALL option to games, demos etc instead of a tag/category/recent
- all sonarqube warnings
- Bug: when selecting random, nothing is selected

IMPROVEMENTS

- Not full Context passing to classes, but smallest scope of context
- lcd cursor commmands

TODOSPI
TODONVS

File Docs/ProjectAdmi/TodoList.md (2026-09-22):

# SHORT TERM

| Stat | Layer(s) | Sub Category | Item | Description |
| --- | --- | --- | --- | --- |
| Todo | M20 | TM1637 | Sending messages | |
| Todo | M30 | TM1637 | Messages | |
| Todo | M40 | TM1637 | Create domain model | |
| Todo | M50 | TM1637 | Create device model | |
| Todo | M60 | TM1637 | Device driver | |
| Todo | M20 | Led Strips | Sending messages | |
| Todo | M30 | Led Strips | Messages | |
| Todo | M40 | Led Strips | Create domain model | |
| Todo | M50 | Led Strips | Create device model | |
| Todo | M60 | Led Strips | Device driver | |
| Todo | M60 | Led Strips | Double buffer? | |
| Todo | M50 | Led Strips | Current Limiting | |
| Todo | M20 | Apps | Application start/stopping | |
| Todo | M20 | Apps | Application resuming | |
| Todo | M70 | LCD2004 | 20x4 format | |
| | | | | |

# MID TERM

| Stat | Layer(s) | Sub Category | Item | Description |
| ---- | --- | --- | --- | --- |
| | MCP23017 | Hardware | Initial Test, I/O, debounce | |
| | 2004 | Hardware | 2004 + MCP23017 | With Level Shifter |
| | I2S | Hardware | LED Strips | |
| | I2S | Hardware | Speaker Hardware | Initial Test |
| | I2S | Hardware | Speaker Core/Simulator | |
| | I2S | Hardware | Mic Hardware | |
| | I2S | Hardware | Mic Core/Simulator | |
| | I2S | Hardware | SOLDERING Board | |
| | I2S | Hardware | SOLDERING All | |
| | BART | Cable | Jack Cable Bart | Bart |

# IMPROVEMENTS

| Stat | Layer(s) | Sub Category | Item | Description |
| ---- | --- | --- | --- | --- |
| | M10 | Context | Minimum context | |
| | M20 | Context | Minimum context | |
| | M30 | Context | Minimum context | |
| | M40 | Context | Minimum context | |
| | M50 | Context | Minimum context | |
| | M60 | Context | Minimum context | |
| | All | Destructors | Remove empty destructors (and constructors) | |
| | All | Inline getters | Check if useful | |

# FUTURE

| Stat | Layer(s) | Sub Category | Item | Description |
| ---- | --- | --- | --- | --- |
| | M10 | NVS | For settings/highs scores | + Menu |
| | M20 | NVS | For settings/highs scores | + Menu |
| | M30 | NVS | For settings/highs scores | |
| | M40 | NVS | For settings/highs scores | |
| | M50 | NVS | For settings/highs scores | |
| | M60 | NVS | For settings/highs scores | |
| | M10 | Passive Buzzer | | |
| | M20 | Passive Buzzer | | |
| | M30 | Passive Buzzer | | |
| | M40 | Passive Buzzer | | |
| | M50 | Passive Buzzer | | |
| | M60 | Passive Buzzer | | |
| | M10 | Micro SD Card  | | |
| | M20 | Micro SD Card  | | |
| | M30 | Micro SD Card  | | |
| | M40 | Micro SD Card  | | |
| | M50 | Micro SD Card  | | |
| | M60 | Micro SD Card  | | |
| | M10 | I2S Speaker | | |
| | M10 | I2S Speaker | | |
| | M30 | I2S Speaker | | |
| | M40 | I2S Speaker | | |
| | M50 | I2S Speaker | | |
| | M60 | I2S Speaker | | |
| | ??? | Samples via SD | | |
| | M10 | I2S Microphone | | |
| | M20 | I2S Microphone | | |
| | M30 | I2S Microphone | | |
| | M40 | I2S Microphone | | |
| | M50 | I2S Microphone | | |
| | M60 | I2S Microphone | | |
| | M20 | Applications | Write games, demos etc | |

# DONE

| Stat | Layer(s) | Sub Category | Item | Description |
| --- | --- | --- | --- | --- |
| Done | M50 | LCD2004 | Finish device model | |
| Done | M60 | LCD2004 | Support single char writing  | |
| Done | M60 | I2c | Create device driver | Initialize |
| Done | M60 | LCD2004 | Create device driver | |
| Done | M50 | PinIo | Send input queue messages | |
| Done | M50 | PinIo | Connect to M60 | |
| Done | M60 | MCP23017 | Create device drivers | |
| Done | M20 | PinIO | Process input queue messages | |

# REJECTED

| Rejected | Buttons  | Core         | Debounce | Hardware debouncing |
|         |          |                |                              |                                 |
|         |          |                |                              |                                 |
|         |          |                |                              |                                 |
|         |          |                |                              |                                 |
|         |          |                |                              |                                 |
|         |          |                |                              |                                 |
|         |          |                |                              |                                 |
|         |          |                |                              |                                 |
|         |          |                |                              |                                 |
|         |          |                |                              |                                 |
|         |          |                |                              |                                 |
|         |          |                |                              |                                 |
|         |          |                |                              |                                 |
|         |          |                |                              |                                 |
|         |          |                |                              |                                 |
|         |          |                |                              |                                 |
|         |          |                |                              |                                 |
|         |          |                |                              |                                 |
|         |          |                |                              |                                 |
|         |          |                |                              |                                 |
|         |          |                |                              |                                 |
|         |          |                |                              |                                 |
|         |          |                |                              |                                 |
|         |          |                |                              |                                 |
|         |          |                |                              |                                 |
|         |          |                |                              |                                 |
|         |          |                |                              |                                 |
|         |          |                |                              |                                 |
|         |          |                |                              |                                 |
|         |          |                |                              |                                 |
|         |          |                |                              |                                 |
|         |          |                |                              |                                 |
|         |          |                |                              |                                 |
|         |          |                |                              |                                 |
|         |          |                |                              |                                 |

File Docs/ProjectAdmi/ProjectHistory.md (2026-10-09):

# Project Sizes

# History

Lines with comments

| Date | Oct 2026 | 09-23 | 09-16 | 09-16 | 09-07 | 08-07 | 08-04 | 08-03 | 08-02 | 08-01 | 07-31 | 07-30 | 07-29 | 07-28 | 07-27 | 07-26 | 07-25 |
| --- | ---- | -- | --- | --- | --- | --- | --- | --- | --- | --- | --- | --- | --- | --- | --- | --- | --- |
| M00 | 1236 | 1230 | 1102 | 1102 |  1102 | 634 | 644 | 644 | 646 | 636 | 616 | 572 | 597 | 526 | 320 | 315 | 0 |
| M10 | 1106 | 1106 | 965 | 965 | 965 | 895 | 895 | 895 | 899 | 899 | 867 | 748 | 744 | 577 | 577 | 562 | 632 |
| M20 | 3294 | 3004 | 3119 | 2883 | 2528 | 2271 | 2224 | 2217 | 2168 | 1977 | 1942 | 1916 | 1917 | 1843 | 1843 | 1828 | 1862 |
| M21 | 116 | 116
| M22 | 0 | 0
| M23 | 0 | 0
| M24 | 230 | 230
| M30 | 861 | 850 | 755 | 755 | 746 | 659 | 647 | 647 | 577 | 571 | 485 | 485 | 485 | 170 | 170 | 124 | 124 |
| M40 | 1436 | 1406 | 1112 | 1112 | 1066 | 1062 | 1041 | 1041 | 985 | 1005 | 943 | 931 | 929 | 710 | 374 | 240 | 301 |
| M50 | 1174 | 1139 | 981 | 981 | 962 | 965 | 888 | 888 | 806 | 786 | 779 | 765 | 593 | 346 | 285 | 282 | 413 |
| M60 | 1833 | 1833 | 1465 | 1465 | 1457 | 1386 | 1314 | 1315 | 1209 | 1221 | 1204 | 1685 | 1257 | 910 | 617 | 463 | 160 |
| M70 | 2141 | 2141 | 2140 | 2140 | 2137 | 2133 | 1753 | 1640 | 1537 | 1521 | 1846 | 1844 | 0 | 0 | 0 | 0 | 0 |
| M80 | 2632 | 2660 | 2007 | 2007 | 2009 | 1864 | 1860 | 1820 | 1509 | 1506 | 1450 | 791 | 765 | 678 | 689 | 689 | 689 |
| M81 | 624 | 624
| M90 | 1144 | 1155 | 1130 | 1130 | 1130 | 942 | 847 | 846 | 709 | 709 | 666 | 660 | 557 | 509 | 366 | 353 | 319 |
| --------- | ----- | ----- | ----- | ----- | ----- | ----- | ----- | ----- | ----- | ----- | ----- | ----- | ----- | ----| ---- |
| **TOTAL** |17838 | 17483 | 14776 |  14540 | 14102 | 12811 | 12113 | 11953 | 11045 | 10803 | 10798 | 10397 | 7844 | 6269 | 5241 | 4865 | 4500 |

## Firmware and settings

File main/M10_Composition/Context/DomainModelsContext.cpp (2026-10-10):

#include "../../M40_DomainModels/I2c/Displays/Lcd2004/Lcd2004.hpp"
#include "../../M40_DomainModels/I2c/Displays/Tm1637/Tm1637.hpp"
#include "../../M40_DomainModels/I2c/IoPins/IoPins.hpp"
#include "../../M40_DomainModels/LedStrips/LedStrips.hpp"
#include "../../M40_DomainModels/Spi/MicroSdCard/MicroSdCard.hpp"
#include "../../M40_DomainModels/Audio/Microphone/Inmp1441.hpp"
#include "../../M40_DomainModels/Audio/Dac/Max53987a.hpp"
#include "../../M40_DomainModels/Audio/Buzzer/Buzzer.hpp"
#include "DomainModelsContext.hpp"

DomainModelsContext::DomainModelsContext()
:   _lcd2004(nullptr), 
    _tm1637CentralPanel(nullptr), 
    _tm1637Player1(nullptr), 
    _tm1637Player2(nullptr),
    _ioPins(nullptr), 
    _ledStrips(nullptr),
    _microSdCard(nullptr),
    _microphone(nullptr),
    _dac(nullptr),
    _buzzer(nullptr)
{
}

DomainModelsContext::~DomainModelsContext()
{
}

void DomainModelsContext::Set(
    std::unique_ptr<Lcd2004> lcd2004,
    std::unique_ptr<Tm1637> tm1637CentralPanel,
    std::unique_ptr<Tm1637> tm1637Player1,
    std::unique_ptr<Tm1637> tm1637Player2,
    std::unique_ptr<IoPins> ioPins, 
    std::unique_ptr<LedStrips> ledStrips,
    std::unique_ptr<MicroSdCard> microSdCard,
    std::unique_ptr<Inmp1441> microphone,
    std::unique_ptr<Max53987a> dac,
    std::unique_ptr<Buzzer> buzzer)
{
    _lcd2004 = std::move(lcd2004);
    _tm1637CentralPanel = std::move(tm1637CentralPanel);
    _tm1637Player1 = std::move(tm1637Player1);
    _tm1637Player2 = std::move(tm1637Player2);
    _ioPins = std::move(ioPins);
    _ledStrips = std::move(ledStrips);
    _microSdCard = std::move(microSdCard);
    _microphone = std::move(microphone);
    _dac = std::move(dac);
    _buzzer = std::move(buzzer);
}

Lcd2004& DomainModelsContext::GetLcd2004()
{
    return *_lcd2004;
}

Tm1637& DomainModelsContext::GetTm1637CentralPanel()
{
    return *_tm1637CentralPanel;
}

Tm1637& DomainModelsContext::GetTm1637Player1()
{
    return *_tm1637Player1;
}

Tm1637& DomainModelsContext::GetTm1637Player2()
{
    return *_tm1637Player2;
}

IoPins& DomainModelsContext::GetIoPins()
{
    return *_ioPins; 
}

LedStrips& DomainModelsContext::GetLedStrips()
{
    return *_ledStrips; 
}

MicroSdCard& DomainModelsContext::GetMicroSdCard()
{
    return *_microSdCard; 
}

Inmp1441& DomainModelsContext::GetMicrophone()
{
    return *_microphone;
}

Max53987a& DomainModelsContext::GetDac()
{
    return *_dac;
}

Buzzer& DomainModelsContext::GetBuzzer()
{
    return *_buzzer;
}

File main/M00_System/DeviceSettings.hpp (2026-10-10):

#pragma once

#ifdef ESP_PLATFORM
#include "driver/i2c.h"
#endif // ESP_PLATFORM

#include <cstdint>

/// @brief Device settings for ESP S3.
/// TO DO LATER: Use good values for pin numbers.
class DeviceSettings
{
public:
    static constexpr uint32_t LOG_LEVELS_DEFAULT                       = 0xFFFFFFFF; // Enable all log levels by default    
    
    static constexpr uint8_t  NVS_VERSION                               = 1;
    static constexpr uint8_t  NVS_7_SEGMENTS_BRIGHTNESS_DEFAULT         = 7;

    static constexpr uint32_t UART_BAUD_RATE                            = 921600; // bps
    static constexpr uint16_t UART_RX_BUFFER_SIZE                       = 4096;   // bytes
    static constexpr uint16_t UART_TX_BUFFER_SIZE                       = 4096;   // bytes

    static constexpr uint8_t  PIN_I2C_SDA                               =  38;
    static constexpr uint8_t  PIN_I2C_SCL                               =  39;
    static constexpr uint8_t  PIN_MCP23017_INTERRUPT                    =  40;
    static constexpr uint8_t  PIN_TM1637_CLOCK                          =  41;
    static constexpr uint8_t  PIN_TM1637_CENTRAL_PANEL_DATA             =  15;
    static constexpr uint8_t  PIN_TM1637_PLAYER_1_DATA                  =  16;
    static constexpr uint8_t  PIN_TM1637_PLAYER_2_DATA                  =  17;
    static constexpr uint8_t  PIN_WS2812_DATA                           =  18;
    static constexpr uint8_t  PIN_I2S_BCLK                             =  19;
    static constexpr uint8_t  PIN_I2S_WS                               =  20;
    static constexpr uint8_t  PIN_I2S_DIN                              =  21;
    static constexpr uint8_t  PIN_I2S_DOUT                             =  22;
    static constexpr uint8_t  PIN_BUZZER                              =  23;

    // I2C
    #ifdef ESP_PLATFORM
        static const uint8_t  I2C_PORT                                  = I2C_NUM_0;
    #else
        static const uint8_t  I2C_PORT                                  = 0;
    #endif
    static constexpr uint32_t I2C_FREQUENCY                             = 100'000;
    static constexpr uint8_t  I2C_ADDRESS_MCP23017                      = 0x20;
    static constexpr uint8_t  I2C_ADDRESS_LCD2004                       = 0x27;

    // I2S
    #ifdef ESP_PLATFORM
        static const uint8_t  I2S_PORT                                  = I2S_NUM_0;
    #else
        static const uint8_t  I2S_PORT                                  = 0;
    #endif
    static constexpr uint32_t I2S_SAMPLE_RATE                          = 16000;
    static constexpr uint16_t I2S_BITS_PER_SAMPLE                      = 16;
    static constexpr uint8_t  I2S_CHANNELS                             = 1;

    // MCP23017 PORTS AND PINS
    static constexpr uint8_t  MCP23017_BIT_PLAYER_1_JOYSTICK_UP         =   8;
    static constexpr uint8_t  MCP23017_BIT_PLAYER_1_JOYSTICK_DOWN       =   9;
    static constexpr uint8_t  MCP23017_BIT_PLAYER_1_JOYSTICK_LEFT       =  11;
    static constexpr uint8_t  MCP23017_BIT_PLAYER_1_JOYSTICK_RIGHT      =  14;
    static constexpr uint8_t  MCP23017_BIT_PLAYER_1_JOYSTICK_BUTTON     =  10;
    static constexpr uint8_t  MCP23017_BIT_PLAYER_1_LED                 =   4;

    static constexpr uint8_t  MCP23017_BIT_PLAYER_2_JOYSTICK_UP         =  12;
    static constexpr uint8_t  MCP23017_BIT_PLAYER_2_JOYSTICK_DOWN       =   2;
    static constexpr uint8_t  MCP23017_BIT_PLAYER_2_JOYSTICK_LEFT       =   1;
    static constexpr uint8_t  MCP23017_BIT_PLAYER_2_JOYSTICK_RIGHT      =   0;
    static constexpr uint8_t  MCP23017_BIT_PLAYER_2_JOYSTICK_BUTTON     =  15;
    static constexpr uint8_t  MCP23017_BIT_PLAYER_2_LED                 =   3;

    static constexpr uint8_t  MCP23017_BIT_SYSTEM_BUTTON                =   7;
    static constexpr uint8_t  MCP23017_BIT_PAUSE_LED                    =   6;
    static constexpr uint8_t  MCP23017_BIT_SELECT_LED                   =   5;
    static constexpr uint8_t  MCP23017_BIT_SETUP_LED                    =  13;

    static constexpr uint16_t MAX_LED_STRIPS_CURRENT_CONSUMPTION_IN_MA  = 5000; // mA

    //TODOSPI
    //TODONVS
};

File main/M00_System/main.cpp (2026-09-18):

#ifdef ESP_PLATFORM

#include "Orchestrator.hpp"
#include "../M10_Composition/Context/Context.hpp"
#include "../M10_Composition/Builder/EspBuilder.hpp"
#include "../M20_Applications/ApplicationsTask.hpp"

class Context;

extern "C" void app_main(
    void)
{
    Context context;
    EspBuilder espBuilder(context);
    Orchestrator orchestrator(espBuilder);
    orchestrator.Initialize();
    orchestrator.StartTasks();
}

#endif // ESP_PLATFORM

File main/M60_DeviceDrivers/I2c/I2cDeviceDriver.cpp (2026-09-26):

#include "I2cDeviceDriver.hpp"
#include "../../M90_Utilities/Assert/Assert.hpp"
#include "../../M80_Services/I2c/I2c.hpp"

I2cDeviceDriver::I2cDeviceDriver()
: 
    _port(0),
    _sdaPin(0), 
    _sclPin(0), 
    _frequency(0),
    _i2c(nullptr)
{
}

void I2cDeviceDriver::SetConfiguration(
    uint8_t port, 
    uint8_t sdaPin, 
    uint8_t sclPin, 
    uint32_t frequency)
{
    AssertValidPort(port);
    Assert::IsTrue(
        Types::ETaskId::I2cTask, 
        frequency == 100'000 || frequency == 400'000, 
        "i2c Frequency should be 100 or 400 KHz");

    _port = port;
    _sdaPin = sdaPin;
    _sclPin = sclPin;
    _frequency = frequency;
}

I2c& I2cDeviceDriver::GetI2c()
{
    return *_i2c;
}

void I2cDeviceDriver::SetI2c(
    I2c& i2c)
{
    _i2c = &i2c;
}

void I2cDeviceDriver::AssertValidPort(
    uint8_t port)
{
    Assert::IsTrue(Types::ETaskId::I2cTask, GetI2c().IsValidPort(port), "i2c Port should be I2C_NUM_0 or I2C_NUM_1");
}

void I2cDeviceDriver::Initialize()
{
    Assert::IsTrue(
        Types::ETaskId::I2cTask, GetI2c().ParamConfig(_port, _sdaPin, _sclPin, _frequency), "Failed to param config");
    Assert::IsTrue(
        Types::ETaskId::I2cTask, GetI2c().DriverInstall(_port), "Failed to install I2C driver");
    MarkInitialized();
}
    
void I2cDeviceDriver::Write(
    uint8_t deviceAddress, 
    const uint8_t* data, 
    size_t length)
{
    Assert::IsTrue(
        Types::ETaskId::I2cTask, IsInitialized());
    Assert::IsTrue(
        Types::ETaskId::I2cTask, 
        GetI2c().MasterWriteToDevice(_port, deviceAddress, data, length, 1000), "Failed to write to device");
}

void I2cDeviceDriver::Read(
    uint8_t deviceAddress,
    uint8_t* data,
    size_t length)
{
    Assert::IsTrue(
        Types::ETaskId::I2cTask, IsInitialized());
    Assert::IsTrue(
        Types::ETaskId::I2cTask, 
        GetI2c().MasterReadFromDevice(_port, deviceAddress, data, length, 1000), "Failed to read from device");
}

uint8_t I2cDeviceDriver::ReadRegister(
    uint8_t deviceAddress, 
    uint8_t registerAddress)
{
    Assert::IsTrue(Types::ETaskId::I2cTask, IsInitialized());

    uint8_t value = 0;
    void* cmd = GetI2c().CmdLinkCreate();
    Assert::IsNotNullptr(Types::ETaskId::I2cTask, cmd, "CmdLinkCreate");

    // Write register address
    Assert::IsTrue(Types::ETaskId::I2cTask, GetI2c().MasterStart(cmd), "Failed master start");
    Assert::IsTrue(
        Types::ETaskId::I2cTask, 
        GetI2c().MasterWriteDeviceAddress(cmd, deviceAddress), 
        "Failed to write device address");
    Assert::IsTrue(
        Types::ETaskId::I2cTask, 
        GetI2c().MasterWriteRegisterAddress(cmd, registerAddress),
        "Failed to write register address");

    // Read one byte
    Assert::IsTrue(
        Types::ETaskId::I2cTask, GetI2c().MasterStart(cmd), 
        "Failed master start 2");
    Assert::IsTrue(
        Types::ETaskId::I2cTask, 
        GetI2c().MasterWriteDeviceAddress(cmd, deviceAddress), 
        "Failed to write device address 2");
    Assert::IsTrue(
        Types::ETaskId::I2cTask, 
        GetI2c().MasterReadByte(cmd, &value),
         "Failed to read value");
    Assert::IsTrue(
        Types::ETaskId::I2cTask, 
        GetI2c().MasterStop(cmd), 
        "Failed master stop");

    Assert::IsTrue(
        Types::ETaskId::I2cTask, GetI2c().MasterCmdBegin(_port, cmd, 10),
        "Failed to master cmd begin");
    GetI2c().CmdLinkDelete(cmd);

    return value;
}

void I2cDeviceDriver::ReadRegister(
    uint8_t deviceAddress, 
    uint8_t registerAddress,
    uint8_t* data,
    size_t length)
{
    Assert::IsTrue(Types::ETaskId::I2cTask, IsInitialized());

    void* cmd = GetI2c().CmdLinkCreate();
    Assert::IsNotNullptr(Types::ETaskId::I2cTask, cmd, "CmdLinkCreate");

    // Write register address
    Assert::IsTrue(Types::ETaskId::I2cTask, GetI2c().MasterStart(cmd), 
        "Failed master start");
    Assert::IsTrue(
        Types::ETaskId::I2cTask, 
        GetI2c().MasterWriteDeviceAddress(cmd, deviceAddress), 
        "Failed to write device address");
    Assert::IsTrue(
        Types::ETaskId::I2cTask, 
        GetI2c().MasterWriteRegisterAddress(cmd, registerAddress), 
        "Failed to write register address");
    
    // Read data
    Assert::IsTrue(Types::ETaskId::I2cTask, GetI2c().MasterStart(cmd), "Failed master start 2");
    Assert::IsTrue(
        Types::ETaskId::I2cTask, GetI2c().MasterWriteDeviceAddress(cmd, deviceAddress), 
        "Failed to write device address 2");
    Assert::IsTrue(Types::ETaskId::I2cTask, GetI2c().MasterRead(cmd, data, length), "Failed to read value");
    Assert::IsTrue(Types::ETaskId::I2cTask, GetI2c().MasterStop(cmd), "Failed master stop");
    
    Assert::IsTrue(Types::ETaskId::I2cTask, GetI2c().MasterCmdBegin(_port, cmd, 10), "Failed to master cmd begin");
    GetI2c().CmdLinkDelete(cmd);
}

void I2cDeviceDriver::WriteRegister(
    uint8_t deviceAddress,
    uint8_t registerAddress,
    uint8_t value)
{
    Assert::IsTrue(Types::ETaskId::I2cTask, IsInitialized());

    void* cmd = GetI2c().CmdLinkCreate();
    Assert::IsNotNullptr(Types::ETaskId::I2cTask, cmd, "CmdLinkCreate");

    Assert::IsTrue(Types::ETaskId::I2cTask, GetI2c().MasterStart(cmd), "Failed master start 2");
    Assert::IsTrue(
        Types::ETaskId::I2cTask, 
        GetI2c().MasterWriteDeviceAddress(cmd, deviceAddress), 
        "Failed to write device address 2");
    Assert::IsTrue(
        Types::ETaskId::I2cTask, 
        GetI2c().MasterWriteRegisterAddress(cmd, registerAddress), 
        "Failed to write register address 2");
    Assert::IsTrue(
        Types::ETaskId::I2cTask, 
        GetI2c().MasterWriteByte(cmd, value), 
        "Failed to write value");
    Assert::IsTrue(
        Types::ETaskId::I2cTask, 
        GetI2c().MasterStop(cmd), 
        "Failed master stop");

    Assert::IsTrue(
        Types::ETaskId::I2cTask, 
        GetI2c().MasterCmdBegin(_port, cmd, 10), 
        "Failed to master cmd begin");
    GetI2c().CmdLinkDelete(cmd);
}
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

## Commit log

2026-07-01 Fixed joysticks on Windows
    [main.cpp]
2026-07-02 Fixed hovering for button/joystick, created temp led
2026-07-03 Multiple instances for buttonsd
2026-07-03 Gdi LEDs, fixed bug in GetPort/Pin
2026-07-04 Removed software bouncing, Fixed RTos, Added Timer, Added Hardware
    [0603 Resistor.FCStd, 1506_light_profile.stp, 1602_lcd.stl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]
2026-07-05 Removed timer, use get ticks from RTos
2026-07-07 Led Strip classes
2026-07-07 ESP32 WS2812 RMT code
2026-07-07 Improved Menu joystick/button directions, removed BecamePressed/GetJoystickDirection
2026-07-09 Removed Interfaces, added ComponentsBuilder, split led strips into model/driver
2026-07-09 Combined Led Strip files
2026-07-10 System and Led Strip task working, no queries yet
2026-07-10 Current limiter for LED stripst
2026-07-10 Inline accessors, small cleanups, removed empty destructors
    [1DGames.kicad_sch, I2S.kicad_sch, players.kicad_sch]
2026-07-10 Random, improved Led strip simulation
2026-07-15 RTOS message to LedStrip working, rough version
2026-07-17 Apps/Driver buffer for LED Strips
2026-07-21 Replaced 1602 to 2004 in Kicad and Tinkercad
    [1DGames.kicad_pcb, I2S.kicad_sch, Kolíková lišta přímá krátká - 2,54mm.SLDPRT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]
2026-07-21 Made everything compilable by commenting issues. BREAKS OUTPUT. Added UML diagrams for new architecture
    [main.cpp]
2026-07-23 New architecture, L1 composition finished, probably, on ESP32
    [1DGames.kicad_pcb, 1DGames.kicad_sch, 1DGames.sch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]
2026-07-25 Fixed 16-20 char LCD in menu, split L8/L9
    [Assert.cpp]
2026-07-25 Removed Rtos from tasks/queues, initialization of device models
2026-07-27 Changed Input/OutputQueue(Reader) to I2c...
2026-07-28 Part of device driver, setting of input mask
2026-07-28 led from L4 to L5
2026-07-28 timer utility, sending gpio from L5 -> L6 mcp
2026-07-28 Interrupt handler read
2026-07-28 Send messages to input queue for i2c
2026-07-29 TM1637 Device driver and related, dirty flags
2026-07-29 Led Strips upto L4
2026-07-30 Led strips L5
2026-07-30 constexpr, and fixed issue in ws28xx L5 brightness control
    [DeviceSettings.hpp]
2026-07-30 Adapted dirty, busy with driver platform specific removal
2026-07-31 I2c platform independent, added servvice I2c in L8
2026-08-01 Windows build, fixed various contruction errors, unfinished
    [Assert.cpp, Builder.cpp, DeviceSettings.hpp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]
2026-08-01 Changed Debug to Log, fixed queue construction, added queue procesor
    [Assert.cpp, Builder.cpp, Simulator.cpp]
2026-08-01 Fixed queues again, queue lengths/item size, space for LCD lines
    [Builder.cpp]
2026-08-01 Restructured L7, first enclosure shown
2026-08-02 Fixed issue in TM1637, removed Displays class
    [Builder.cpp, DomainModelsContext.cpp, I2cTaskDeviceDriversDelegate.cpp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]
2026-08-02 Led strips work, started with parameters on new lines
2026-08-04 Broken code, halfway joystick gdi
    [1DGames.kicad_pcb, 1DGames.kicad_sch, Calc.ods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]
2026-08-07 Fixed system button issues
2026-08-07 Many sonar issues solved, made faster
2026-08-08 GDI thread, updating
2026-09-12 Added Kicad proto board
    [1DGames.kicad_pcb, 1DGames.kicad_sch, 1DGames.sch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]
2026-09-15 New Fraxis PCB layout
    [.kicad_sch, 1DGames.kicad_pcb, 1DGames.kicad_sch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]
2026-09-17 During highscores
    [1DGames.kicad_pcb]
2026-09-20 Add NVS service for settings/high scores storage
    - Add Nvs base interface with read/write methods for various data types
    - Add EspNvs implementation for ESP32 platform using nvs_flash
    - Add WindowsNvs stub implementation for simulator
    - Integrate NVS into ServicesContext and Builder
    - Initialize NVS in Orchestrator
    - Update CMakeLists.txt and Visual Studio project files
    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
2026-09-21 Add SPI support for ESP32 IDF with MicroSD module
    - Add SPI service interface (M80_Services/Spi/Spi.hpp, Spi.cpp)
    - Add ESP32 SPI implementation (EspSpi.hpp, EspSpi.cpp)
    - Add Windows SPI implementation (WindowsSpi.hpp, WindowsSpi.cpp)
    - Add MicroSD domain model (M40_DomainModels/Spi/MicroSd/)
    - Add MicroSD device model (M50_DeviceModels/MicroSd/)
    - Add MicroSD device driver (M60_DeviceDrivers/MicroSd/)
    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
2026-09-21 Refactor NVS into separate RTOS task with message queue
    - Add NvsQueue message type for NVS read/write operations
    - Add NvsTask RTOS task similar to I2cTask
    - Add NvsQueueReader and NvsQueueWriter for processing messages
    - Integrate NvsTask into TasksContext, Builder, and Orchestrator
    - Add NvsQueue to QueuesContext and Builder
    This allows NVS operations to be handled asynchronously via
    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
2026-09-22 NVS including task/queues, SPI without task/queues; all unused yet
2026-10-08 Added safety in Kicad power, added NVS read version/tm1637 brightness
    [main_power.kicad_sch, power.kicad_pcb, power.kicad_sch]
2026-10-08 Led strips brightness from NVS
2026-10-10 Add audio module with I2S support for INMP1441 microphone and MAX53987A DAC
    - Add Types.hpp enums for audio devices (EAudioDeviceId, EBuzzerId, EAudioSampleId, EAudioChannel)
    - Add I2S service interface and ESP32/Windows implementations
    - Add PWM service for buzzer control
    - Add Audio domain models (Audio, Inmp1441, Max53987a, Buzzer)
    - Add Audio device models for all audio components
    - Add Audio device drivers (AudioDeviceDriver, Inmp1441DeviceDriver, Max53987aDeviceDriver, BuzzerDeviceDriver)
    - Add Audio messages and queues (AudioInputQueue, AudioOutputQueue)
    - Add Audio RTOS task and task device drivers delegate
    - Add WAV file handling and audio mixer
    - Add SD card audio file storage/play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
    [Builder.cpp, DeviceDriversContext.cpp]
2026-10-12 Added I2s but fully untested, compiles for both ESP32/Windows
2026-10-27 Clang format/tidy, removed many sonar issues, added pragma
2026-10-30 Unit tests framework, cmd only (test explorer does not work
2026-10-30 Unit tests framework, partly working
2026-11-05 Windows Google test frameworks work in test explorer, added Assert unit tests
2026-11-13 Split set methods, more init tesets, some failing (I2c)
